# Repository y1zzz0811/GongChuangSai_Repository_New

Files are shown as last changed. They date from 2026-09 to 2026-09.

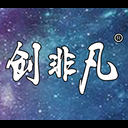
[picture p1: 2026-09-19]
参考资料/参考代码/视觉识别/视觉代码gxwl4看1抓1/app.png

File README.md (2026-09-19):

# 工创赛 · 智能物流搬运机器人

本仓库用于「中国大学生工程实践与创新能力大赛（工创赛）」智能物流搬运赛道的团队协作与代码、资料管理。

## 项目简介

智能物流搬运机器人，基于 STM32F407 主控，集成双轴机械臂、物料转台、麦克纳姆轮底盘与视觉系统，实现物料的自主识别、抓取与搬运。

## 目录结构

| 目录 | 说明 |
| --- | --- |
| [`代码`](代码) | 项目自行开发的源代码（当前为空） |
| [`设计图`](设计图) | 项目自行设计的三维模型与图纸（当前为空） |
| [`参考资料`](参考资料) | 参考代码、参考设计图、课程讲义、芯片手册、开源方案等 |
| [`规则说明与注意事项`](规则说明与注意事项) | 赛事规则、注意事项与团队约定 |

## 使用说明

- 嵌入式工程使用 Keil MDK-ARM 开发；编译中间产物已通过 `.gitignore` 忽略。
- 提交前请先 `git pull` 拉取最新代码，减少冲突。

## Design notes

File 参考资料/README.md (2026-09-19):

# 参考资料

存放学习与开发参考资料。

- [`参考代码`](参考代码)：STM32 例程、视觉识别例程等
- [`参考设计图`](参考设计图)：三维模型、装配体等
- 芯片手册、课程讲义、软件工具等

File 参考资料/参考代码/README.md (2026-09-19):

# 参考代码

存放用于参考的示例代码（当前项目尚未开始实际开发）。

- 嵌入式固件：STM32F407（Keil MDK-ARM / RT-Thread / HAL 库）
- 视觉与算法脚本：Python（MaixCAM）

> 编译中间产物（`.o`、`.axf`、`.hex`、`Objects/`、`Listings/` 等）已通过根目录 `.gitignore` 忽略，请勿手动提交。

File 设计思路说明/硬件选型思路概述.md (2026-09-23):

# 工创赛物流搬运小车硬件选型思路概述

## 一、总体选型思路

本次硬件选型并不是单纯追求“性能最高”的器件，而是在 **比赛任务需求、整车空间与重量、控制精度、开发难度和总体预算** 之间做平衡。2027 年智能搬运赛项要求机器人能够完全自主完成定位、移动、避障、二维码读取、物料颜色与位置识别、抓取、载运和精准放置等任务，因此视觉、机械执行和底盘定位三部分都需要具备足够的可靠性与可重复性。同时，规则对出发尺寸、单电源供电以及补光方向等也有明确限制，因此硬件必须兼顾集成度、体积和工程实现难度。

目前方案的核心思路可以概括为：**视觉部分优先追求单位预算下的有效算力和多摄像头扩展能力；机械臂部分优先考虑执行器重量、尺寸、速度和定位精度与塔吊式结构的匹配；底盘部分则优先保证运动控制和航向定位精度，在预算范围内尽量提高定位稳定性。**

---

## 二、视觉模块选型思路

视觉系统需要承担两类任务：一处摄像头负责二维码读取、障碍物识别及部分车身视觉定位；另一处摄像头负责物料颜色、物料位置、色环和放置位置识别。因此视觉方案的主要矛盾不是单纯“能不能识别”，而是 **如何在有限预算下同时完成两路视觉任务，并给后续算法留出一定性能余量**。

我们重点比较了 OpenMV、K230、MaixCAM 以及树莓派一类 SBC（Single Board Computer，单板计算机）视觉方案。OpenMV 的优势是生态成熟、开发简单，但在价格与 K230 接近的情况下，K230 的计算性能和后续扩展能力更强；MaixCAM 的性能和软件生态也较好，但整体价格更高；树莓派等 Linux 单板计算机的通用性最强，但主板、摄像头、存储和供电等整体成本明显增加，不符合当前视觉预算。

因此当前更倾向 **01Studio K230 + 双 GC2093 摄像头**。K230 的一个重要优势是单板具备多摄像头接口资源，可以让一块视觉板同时承担车身视觉和夹爪视觉两部分任务，从而减少额外视觉主控的数量，压缩成本和体积。现阶段的思路是先尝试由一块 K230 完成两路视觉处理；如果实际测试发现两路同时运行时会明显降低帧率或影响识别稳定性，则优先通过软件调度将两路任务错峰执行，因为扫码、障碍物识别、物料抓取和放置本身并不一定在同一时刻发生。若二维码识别仍然占用过多计算资源，也可以增加 GM65 等专用扫码模块，将二维码任务从主视觉中剥离，使 K230 主要负责颜色、位置和几何特征识别。

所以视觉部分的核心选型逻辑是：**先利用 K230 的高性价比和多摄能力实现一板双摄，在满足识别效果的前提下尽量减少视觉主控数量；若性能不足，再优先通过任务分时或专用扫码模块进行功能拆分，而不是一开始就增加更昂贵的计算平台。**

补光方面，由于比赛规则只允许垂直向下补光，因此补光主要服务于下视物料与色环识别，采用 LED 补光模块稳定照明环境，减小赛场光照和物料色差对颜色识别的影响。前视二维码部分不采用主动前向补光，而更多依靠曝光、增益和图像算法优化。

---

## 三、机械臂电机与舵机选型思路

我们的机械执行机构并不是传统多关节串联机械臂，而是更接近 **塔吊式直线运动结构**，主要包含竖直升降、水平伸缩、整体 Yaw 旋转、夹爪开合以及托盘转动。因此执行器选型不能简单套用“机械臂全部用同一种电机”的思路，而需要针对不同运动轴分别考虑。

这一部分主要关注四个因素：

1. **电机自重及其对机构平衡和惯量的影响。**  
   塔吊结构的运动部件越轻，升降和伸缩时所需驱动力越小，启停振动也越容易控制。尤其是水平伸缩轴，电机和夹爪如果过重，会明显增加悬臂负担。因此在满足扭矩的前提下，应尽量使用更小、更轻的执行器。

2. **电机体积是否与机械结构匹配。**  
   2027 规则要求机器人出发时投影尺寸不超过 300 mm × 300 mm、高度不超过 400 mm，因此初始收纳空间有限。28、35、42 等不同规格步进电机在尺寸和重量上的差异会直接影响机械设计和整车布置。

3. **定位精度和重复性。**  
   物料最终放置位置按照圆环精度评分，因此机械臂各轴不仅要“能运动到附近”，更重要的是重复到达同一位置时误差要足够小。闭环步进电机自带编码反馈，可以降低丢步风险，更适合升降、伸缩和旋转这类需要明确位置控制的轴。

4. **动作速度。**  
   比赛整体有时间要求，因此夹爪等只需要在少数固定位置之间动作的机构，没有必要全部采用较重的步进系统。高速舵机结构简单、自带位置闭环，适合夹爪开合和托盘旋转等动作。

基于这些考虑，目前方案采用分轴选型：  
- **Yaw 轴：42 闭环步进电机**，重点保证整体旋转定位的重复性；若后续发现重量对机构影响较大，可考虑高速大扭矩舵机作为减重备选。  
- **Z 轴升降：35 闭环步进电机**，升降负载中等，在重量和扭矩之间取平衡。  
- **水平伸缩：28 闭环步进电机**，该轴位于运动机构上，对轻量化更敏感，因此优先采用更小规格的电机。  
- **夹爪开合：10 kg 级高速舵机**，物料质量不超过 100 g，夹爪所需扭矩并不大，高速舵机可以减少开合动作时间，同时避免在末端增加过多重量。  
- **托盘旋转：25 kg 级舵机**，托盘需要带动物料并克服一定转动惯量，因此选择更高扭矩型号以保证动作稳定。

整体思路是：**需要连续精确位置控制的轴优先用闭环步进，需要快速完成固定角度动作的机构优先用舵机；越靠近运动末端，越重视轻量化。**

---

## 四、底盘控制与定位选型思路

底盘方案采用 **80 mm 麦克纳姆轮 + 4 个 42 闭环步进电机**。麦克纳姆轮能够实现前后、横移和原地旋转三自由度运动，非常适合在赛道内进行小范围调姿和视觉对位；闭环步进则兼顾了低速控制、位置重复性和防丢步能力，在有限预算下比普通开环步进更适合作为精准移动平台。

之所以优先考虑底盘运动精度，是因为比赛最终不是只考“能否到达目标区域”，而是直接按照物料放置的圆环位置评分。规则中 1 环为 15 分，而随着偏差增大分数快速下降，因此车体停车位置、车身航向误差和机械臂末端位置都会直接转化为得分差异。也就是说，**底盘定位精度本身就是评分链条的一部分，而不是单纯的辅助性能。**

航向定位目前选择 **JY901S 九轴 IMU**。我们也比较过 HWT101 一类更偏向 AGV 航向测量的模块，HWT101 在零漂等性能上更有优势，但价格超出当前预算，因此现阶段选择 JY901S，在成本与性能之间折中。JY901S 可以直接输出融合后的航向角，配合底盘控制用于直线行驶修正和转向角度闭环。

这里需要强调的是，IMU 主要用于 **车身航向角 θ 的测量**，并不能独立解决 X、Y 平面位置。闭环步进编码器反映的是电机轴运动，在麦克纳姆轮发生打滑时也不能完全等价于车体真实位移。因此目前方案将其作为基础定位手段，同时给后续升级留出接口：如果测试中发现累计位置误差较大，可以进一步加入视觉辅助定位、独立编码轮等手段，通过多源信息对车体位置进行修正。

所以底盘与定位部分的总体思路是：**先依靠闭环步进保证运动执行精度，依靠 IMU 保证航向稳定，再根据实车误差决定是否增加外部位置反馈；优先把有限预算投入到真正影响停车和放置精度的环节。**

---

## 五、三部分方案之间的整体关系

视觉、机械执行和底盘定位三部分并不是独立选型，而是围绕“精准抓取—精准运输—精准放置”这一完整任务链协同设计：

- **视觉系统**负责回答“目标是什么、目标在哪里”；
- **底盘与 IMU**负责把机器人稳定地移动到目标附近，并保持正确车身姿态；
- **机械臂执行机构**负责在目标区域内完成精确抓取、升降、伸缩和放置。

在当前预算条件下，我们没有单纯选择性能最高的器件，而是优先寻找 **性能刚好覆盖任务需求、同时具有较好性价比和工程可实现性的方案**。K230 通过一板双摄降低视觉系统成本；不同尺寸的闭环步进电机根据各运动轴负载进行分级配置，减少不必要的重量；夹爪和托盘采用舵机降低结构复杂度；底盘则通过闭环步进与 IMU 提升运动和航向控制精度。

因此这套硬件方案的核心并不是某一个器件本身，而是 **在预算、性能、重量、空间和开发复杂度之间进行系统级取舍，并为后续实车测试后的升级保留余量**。第一阶段先保证整车可以稳定完成任务，再根据实际测试结果重点优化视觉并发性能、底盘累计定位误差以及机械臂各轴速度与精度，从而逐步提高整车比赛表现。

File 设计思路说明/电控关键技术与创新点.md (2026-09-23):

# 电控关键技术与创新点

智能物流搬运赛项 · 电控说明  
依据目前已讨论的底盘、机械臂、避障和软件方案。尚未装车。雷达型号、步进当量仍待实机填写，下面不把这些写成已经完成的技术。本方案不使用灰度传感器。

```mermaid
flowchart TB
    subgraph topRow[" "]
        direction LR
        startNode[一键启动] --> scan[启停区扫描] --> match{有对应路段}
    end
    subgraph botRow[" "]
        direction LR
        stay[留在启停区]
        lock[锁定路段] --> task[沿灰道搬运] --> back[返回同一启停区]
    end
    match -->|没有| stay
    match -->|有| lock
    style topRow fill:none,stroke:none
    style botRow fill:none,stroke:none
```

一次运行只锁定一套路段。锁定之后按任务顺序走完，中途不再改路。

```mermaid
flowchart TB
    subgraph coarseRow[" "]
        direction LR
        park[停在工位外侧] --> coarse[机械臂回转并伸出] --> hold[机械臂保持]
    end
    subgraph fineRow[" "]
        direction LR
        fine[底盘慢速平移] --> lockChassis[底盘锁定] --> drop[垂直升降]
    end
    hold --> fine
    style coarseRow fill:none,stroke:none
    style fineRow fill:none,stroke:none
```

粗对准使用标定角度和伸出量。细对准只移动底盘，放下之后不再推移物料。

---

## 1. 关键技术

电控集中在 STM32F407 上，用定时器和主循环分工，不把图像放进主控。

**底盘运动。** 四轮麦克纳姆轮以前进、横移、旋转为控制量，逆解到四轮；某轮超速时四轮同比缩小，避免方向被拉偏。闭环由内到外是轮速、航向和工位视觉。直道靠陀螺仪保持航向、编码器估计路程。不使用灰度传感器。

**任务与路线。** 任务顺序固定：读码、装载、粗加工、暂存、第二批、码垛、回到本次出发的启停区。障碍落在某条车道上，该车道即被堵死。车道数量有限，所以堵法的总数有限，但当前还不能确定具体有几种。路段表按实际堵法预先写好，启动后锁定一套，行驶中不重新计算。

**视觉。** 两路 K230 分开使用。侧视读二维码，并在出发前确认视场内的黑色圆柱。向下摄像头只在细对准时给出颜色，以及物料中心或圆环中心相对夹持点的像素偏差。结果打成带校验的串口帧，校验失败的帧丢掉。

**避障感知。** 二维激光雷达在车身不动时扫描一周，用约 50 mm 的弦长判断目标落在哪条车道。侧视只辅助确认自己看得到的候选。转盘和台面挡住的方向记为未看到。

**机械臂。** 回转用 42 步进，伸缩用 28 步进，升降用 35 步进，开合用舵机。三轴按柱坐标控制，升降按二倍程把末端位移算成主动件的 2 倍。位置以归零开关为起点的步数。粗对准用标定角度和伸出量，细对准不再转动手臂。

**安全互锁。** 机械臂动作和托盘旋转时底盘速度为零。细对准结束后才垂直下降。物料接触台面并松爪后，不再推移该件。显示任务码、抓取数和放置数，字符高度不小于 12 mm。

---

## 2. 创新点

**用有限路段表代替行驶中的重新规划。** 障碍出现在某条车道上，就把该车道堵死，只走剩余车道。车道数有限，堵法总数也就有限；具体有几种要等场地车道确定后再填进路段表，当前不写死组合编号。一次运行在出发前锁定与本次堵法对应的那一套，任务顺序不变。结果对不上已有路段，或行驶中与锁定结果矛盾，就停在灰色车道内，不临时改道。

**出发前静止扫描，而不是开到路口再看。** 启停区与出发投影都是 300 mm × 300 mm，原地转向会把车角带出蓝区。雷达自己转一周完成四周测距，底盘速度保持为零。摄像头视场盖不住四周，所以由雷达判断哪条车道被堵，摄像头只确认视场内的黑色圆柱。没有回波不当成通路。判别结果对不上已有路段，就留在启停区。

**被堵住的车道直接删除，不从障碍旁边挤过。** 灰色车道宽 400 mm。障碍位于车道中部时，两侧剩余宽度不足以让车身留在灰道内通过。电控因此不做贴障横移，只在剩余车道上选择已经写好的路段。障碍具体会出现在哪些车道，当前不作规定。

**粗对准和细对准分开，细对准时手臂不动。** 底盘先停在工位外侧，机械臂回转到工位角度并伸到接近半径，摄像头和夹爪的相对位置随之固定。剩余偏差只由底盘按向下摄像头慢速平移消除。细对准若再转手臂，摄像头会跟着动，和挪底盘一样都在改画面，所以这一段不叠加回转或伸缩。对准后锁定底盘，手臂垂直升降。1 环只有很小的径向余量，而且接触台面后不能再推，所以放环用更低的速度，并在松爪后直接升起。

**灰色车道上不循黑线。** 行驶方向靠陀螺仪，路程靠编码器，工位毫米级偏差靠向下视觉。这样直道速度和放环精度可以分开，不会用同一套循迹速度去对圆环。

**机械臂按柱坐标和二倍程控制。** 回转、伸缩、升降分别对应角度、半径和高度，主控不做多关节逆解。二倍程只改末端与主动件的比例。三层环形爪由一只舵机开合，直径和倾角不单独控制。取放点只有车上托盘的直角顶点，换料靠托盘旋转。

---

## 3. 计划书正文（写入 Word）

电控的创新点集中在路径选择和放置精度。障碍落在某条车道上则该车道堵死，各种堵法数量有限，出发前由激光雷达与侧视一次判别并锁定对应路段，行驶中不再改线，也不贴障通过。机械臂完成粗对准后保持姿态，底盘再按向下摄像头消除剩余偏差，锁定后垂直放下，使物料对准圆环且放下后不再推移。

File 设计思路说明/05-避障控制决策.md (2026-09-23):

# 避障控制决策方案

智能物流搬运赛项 · 电控设计稿  
状态：理论方案。雷达型号、扫描面高度、各车道区域和遮挡角均不在本文写死，装车并对照场地图后写入配置。

---

## 1. 设计前提

离开启停区后，底盘只在灰色车道上行驶，不进入白色或淡黄色区域。中间为十字灰色车道，宽 400 mm。

黑色圆柱障碍的尺寸为直径 50 mm、高 100 mm。障碍会出现在哪些车道，当前还不能确定。障碍在车道中部时，两侧空档不足以让车身留在灰道内绕过，因此不贴障通过。某条车道上出现障碍，该车道从本次地图中删除。

蓝色启停区有两处，抽签决定出发位置，返回同一处。车道数量有限，因此堵死组合的总数有限，但当前不能确定具体有几种，本文不列出组合编号。路段表按「出发位置 + 被堵车道」在车道确定后填写，一次运行只锁定一套。任务顺序不变，路段航向和距离在标定后填写。

感知为侧视 K230 加二维激光雷达。一键启动后、底盘仍在蓝色启停区内完成一次扫描，然后锁定路线。

```mermaid
flowchart TB
    subgraph obsTop[" "]
        direction LR
        see[车道上有障碍] --> block[删除该车道] --> table{能查到路段}
    end
    subgraph obsBot[" "]
        direction LR
        go[锁定后出发]
        again{再扫后能查到}
        again -->|能| go
        again -->|不能| stopNode[停在启停区]
    end
    table -->|能| go
    table -->|不能| again
    style obsTop fill:none,stroke:none
    style obsBot fill:none,stroke:none
```

车身不从障碍旁边挤过。锁定之后，行驶中不再更换路段。

---

## 2. 可行性

这个扫法可以用来锁定路线。它成立的范围是：发令时障碍已经立在车道上，并且雷达从该启停区能直接打到它们。

**扫描时车身不动。** 出发投影不大于 300 mm × 300 mm，启停区也是 300 mm × 300 mm。车身接近这个尺寸时，原地转向会把车角带出蓝区。扫描期间 vx、vy、ωz 都保持为 0。四周距离由雷达自身旋转一周得到，不靠底盘转向。

**扫描面落在圆柱中下部。** 圆柱只有 100 mm 高，扫描面高于此就打空。原料转盘高 80–100 mm、直径 300 mm，粗加工台和暂存台的台体同样会挡住扫描面后方的空间。被挡住的方向没有回波，记为未看到，不记为该方向可通行。转盘和二维码板的位置在规定范围内变化，两种出发位置的遮挡角分开标定。

**50 mm 的短弦和场地装置可以分开。** 距离 1.5 m 时，直径 50 mm 的圆柱张角约 1.9°；距离 2 m 时约 1.4°。所选雷达在最远标定距离上，对这个圆柱至少给出 2 个回波，弦长才稳定。转盘的可见弦长在 300 mm 量级，台面边为 150 mm 与 580 mm，二维码板为竖立 A4，这些回波不作为删车道的依据。雷达装在车内，出发时整车仍在 300 mm × 300 mm × 400 mm 以内。雷达只测距，不照亮场地。

**摄像头确认视场内的候选，不负责看全四周。** 侧视固定在车上，停车时只有一个视场。雷达候选落在该视场内时，再用黑色直立圆柱的外形确认，两者一致才把该点所在车道记为堵住。候选在视场外时，用雷达弦长、所在车道区域，以及离开台面屏蔽区这三条一起判定，并要求连续两圈落到同一条车道。台面角点也可能呈现接近 50 mm 的短弦，所以短弦还必须落在车道的标定区域内、并位于台面屏蔽区之外。

**使用前提。** 命题写明障碍的数量和位置由抽签放置，没有写摆上的时刻，也没有写一定会落在哪几条车道。本方案按「开始扫描时障碍已经在车道上」实施。若现场在车辆离开启停区之后才摆障碍，这次扫描无效。

**扫不清就留在启停区。** 被堵车道都能归入已有路段表时，才锁定路段并出发。否则在启停区内再扫一圈。第二圈仍不能对应，就停在启停区，不进入未确认的车道。

---

## 3. 地图与路线表

车道在标定场地图时编号。车道名字、工位属于哪条车道、每种出发位置下雷达坐标到场地坐标的变换，都在那时确定。当前不规定障碍一定出现在哪几条车道，也不规定一次有几处。

查表键为「出发位置 + 被堵车道的集合」。某种堵法若使某一工位无法沿剩余车道到达，该组合标为不可用，车留在启停区。组合总数有限，具体几种在车道确定后写入，本文不列表。

任务顺序仍为：读取二维码，原料区装载，粗加工区放置并取回，暂存区平面放置，第二批装载、放置并取回，暂存区码垛，返回本次启停区。

---

## 4. 一次扫描如何归入车道

雷达输出一圈的角度和距离。相邻点角度间断超过标定间隙，或距离突变，就分成不同的簇。一簇两端点的弦长为

```
d = sqrt(r1^2 + r2^2 - 2 * r1 * r2 * cos(dθ))
```

弦长落在圆柱标定区间内的簇作为候选。簇的代表点取平均距离和平均角度，再变到场地坐标：

```
x = r * cos(θ + θ_mount)
y = r * sin(θ + θ_mount)
X = x0 + x * cos(yaw0) - y * sin(yaw0)
Y = y0 + x * sin(yaw0) + y * cos(yaw0)
```

`θ_mount` 是雷达零位相对车头的安装角。`(x0, y0, yaw0)` 是该出发位置在场地中的标定位姿。点落在哪条车道的标定长条内，就归到哪条车道。落在转盘、两处台面或二维码板屏蔽区内的簇丢弃。

落在侧视视场内的候选，交给侧视做黑色圆柱外形判定，判定方法与软件方案中的侧视一致。外形不符则该簇丢弃。

连续两圈归入的车道相同，才进入锁定。

```mermaid
flowchart TB
    subgraph scanTop[" "]
        direction LR
        startNode[读出发位置] --> still[底盘速度为零] --> scan[雷达扫两圈] --> assign[归入车道]
    end
    subgraph scanBot[" "]
        direction LR
        cam{侧视能看到} -->|是| vision[确认圆柱]
        cam -->|否| lidarOnly[按雷达保留]
        vision --> known{两圈一致且有路段}
        lidarOnly --> known
        known -->|是| lock[锁定出发]
        known -->|否| stay[留下或再扫]
    end
    assign --> cam
    style scanTop fill:none,stroke:none
    style scanBot fill:none,stroke:none
```

---

## 5. 行驶中的约束

锁定之后按该路段的航向行驶，陀螺仪保持航向，编码器估计路程。对接物料、对接圆环、机械臂动作和托盘旋转期间底盘锁定。

行驶中若测到的通断与已锁定结果矛盾，停车，留在灰色车道内。不改为贴障通过，也不进入黄区或白区，不在行驶中更换路段。

---

## 6. 计划书正文（写入 Word）

障碍出现在某条车道上，则该车道从本次路线中删除，车身不从障碍旁边挤过。车道数量有限，堵死组合的总数有限，具体有几种在场地确定后写入路段表。一键启动后车辆停在蓝色启停区内，二维激光雷达扫描一周，按约 50 mm 的弦长和标定区域判断被堵车道，侧视摄像头确认视场内的黑色圆柱。连续两圈结果一致且能对应已有路段后锁定，再离开启停区，本轮不再改变。扫描面低于圆柱高度，被转盘或台面挡住的方向记为未看到。结果对不上路段表时，车辆留在启停区。其后底盘只在灰色车道内按锁定路段行驶，对接与机械臂动作期间不因避障转向。

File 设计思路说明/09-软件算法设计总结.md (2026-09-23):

# 软件算法设计总结

智能物流搬运赛项 · 电控  
对应计划书第 9 节。下文只列本项目会用到的算法。尚未装车。本方案不使用灰度传感器，也不做灰度巡线。

图像算法在两路 K230 上运行。STM32F407 做状态机、底盘闭环、雷达归车道和机械臂脉冲，只接收带校验的视觉结果。

```mermaid
flowchart TB
    subgraph srcRow[" "]
        direction LR
        side[侧视] --> frame[校验后的数据帧]
        down[向下摄像头] --> frame
        lidar[激光雷达]
    end
    frame --> mcu[主控状态机]
    lidar --> mcu
    subgraph outRow[" "]
        direction LR
        route[锁定路段]
        chassis[底盘闭环]
        arm[机械臂脉冲]
    end
    mcu --> route
    mcu --> chassis
    mcu --> arm
    style srcRow fill:none,stroke:none
    style outRow fill:none,stroke:none
```

校验失败或当前用不到的帧直接丢掉。侧视负责任务码和黑色圆柱，向下摄像头只在细对准时给出颜色和中心。

```mermaid
flowchart TB
    mode{当前任务}
    mode --> obs[出发前归车道]
    mode --> qr[读码校验]
    mode --> color[抓取取色块中心]
    mode --> ring[放环取环心]
    mode --> stack[码垛取同色中心]
    obs --> lock[查表或留下]
    qr --> show[显示任务码]
    color --> move[底盘平移]
    ring --> move
    stack --> move
```

---

## 1. 路径

**任务状态机。** 顺序固定为读码、装载、粗加工、暂存、第二批、码垛、返回本次启停区。出发位置和障碍只改变所走路段，不改变这个顺序。

**路段查表。** 障碍所在车道视为堵死。车道数有限，堵法总数有限，具体几种等场地确定后再写入。查表键是「出发位置 + 被堵车道」。出发前锁定一套，行驶中不重新规划。结果对不上表，或中途与锁定结果矛盾，就停在灰色车道内。

## 2. 底盘

**麦轮逆解与限幅。** 由前进、横移、旋转求出四轮速度。某一轮超过最大转速时，四轮乘同一比例缩小。

**梯形速度。** 路段行程按加速、匀速、减速行驶。靠近工位改为爬行，放环时再降低速度。

**分层闭环。** 由内到外三层：轮速按编码器偏差调节 PWM；航向按陀螺仪偏差调节旋转；细对准时按向下摄像头的像素偏差调节慢速平移，进入阈值后底盘锁定。没有灰度边界这一层。

## 3. 障碍与视觉

**雷达归车道。** 一圈扫描按角度和距离断点分成点簇，用簇两端的弦长区分直径约 50 mm 的圆柱与转盘、台面。代表点变到场地坐标后，落入某条车道的标定区域即记该车道被堵。转盘和台面的屏蔽区内的点丢掉。看不到的方向记为未看到，不记为通路。连续两圈一致才锁定。

**黑色圆柱外形。** 侧视在视场内做低亮度掩膜，保留面积和长宽比符合直立圆柱的轮廓，用来确认雷达候选。视场外的候选只按雷达规则处理。

**任务码校验。** 侧视读取二维码后，检查是否为四组三位数、数字均在 1 到 6、组间用加号连接。连续两帧相同才采用。1 到 6 对应红、黄、蓝、绿、黑、浅蓝。

**物料颜色与中心。** 向下摄像头对六种颜色做阈值分割，取夹持点附近最大的实心色块。蓝色和浅蓝重叠时用亮度分开。中心用轮廓矩，再减去夹持点像素。

**圆环中心。** 放置前对台面边缘做椭圆拟合，把圆心聚在一起的同心椭圆取平均，作为环心。码垛时改为同色物料的色块中心。

**细对准换算。** 像素偏差只在机械臂已经完成粗对准、回转和伸缩保持不动时使用，换成底盘的慢速平移。机械臂运动过程中的画面丢掉。

**串口校验。** 视觉结果以固定帧头加异或校验上传。校验失败、长度不对，或当前状态不需要视觉时，整帧丢弃。

## 4. 机械臂

**柱坐标脉冲。** 回转、伸缩、升降分别对应角度、半径和高度，目标统一换成步进脉冲。升降末端位移按主动件的 2 倍计算。三只电机为回转 42 步进、伸缩 28 步进、升降 35 步进，开合为舵机。

**梯形步进与归零。** 脉冲间隔按梯形曲线变化。每轴以归零开关为步数零点，上电时先收回伸缩，再回转，最后升降。

**开合时序。** 舵机只有张开、闭合两档。闭合指令发出后保持一段标定时间，才允许上升。

**动作互锁。** 回转前伸缩必须收回、升降必须到安全高度。外伸之后才进入底盘细对准。细对准结束并锁定底盘后，才允许垂直升降。手臂未离开托盘直角顶点时，托盘不旋转。

---

## 5. 计划书正文（写入 Word）

软件算法分为路径、底盘、视觉和机械臂四部分。图像处理在两路 K230 上完成，主控只接收带校验的结果。路径使用状态机查表：障碍堵住的车道被删除，出发前锁定一套路段，行驶中不重新规划。底盘采用麦轮逆解，并以轮速、航向和工位视觉分层闭环，细对准时把像素偏差转为慢速平移。障碍由雷达点簇的弦长归入车道，侧视确认黑色圆柱；向下摄像头用颜色阈值和轮廓中心定位物料与圆环。机械臂按柱坐标生成步进脉冲，升降按二倍程换算，对准后只做垂直运动。

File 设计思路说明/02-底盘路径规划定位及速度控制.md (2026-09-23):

# 底盘路径规划、定位及速度控制方案

智能物流搬运赛项 · 电控设计稿  
轮径、轮距、各段航向与距离均不在本文写死，装车并对照场地图后再填入配置。

---

## 1. 设计目标

底盘在灰色车道内完成全场转运，并在原料区、粗加工区、暂存区为机械臂提供稳定的作业停车。放置圆环的重复精度优先于直道速度。

已确定的相关条件：

- 四轮麦克纳姆轮全向底盘。
- 车上为三角旋转托盘，机械臂只在直角顶点固定工位取放；换料由托盘旋转完成。
- 场地原料转盘由赛会提供，与车上托盘无关。
- 向下摄像头负责颜色与物料、圆环定位；侧视摄像头负责二维码与障碍。侧视辅助定位保留接口，暂时不启用。
- 避障为侧视摄像头加二维激光雷达，在离开启停区前扫描一次并锁定路段。

---

## 2. 坐标系与运动学

原点取底板几何中心，X 为前进方向，Y 为向左横移，Z 向上。车体指令为前进速度 vx、横移速度 vy、旋转角速度 ωz。

轮系采用 X 型镜像布置。四轮线速度（左前、右前、左后、右后）：

```
v1 =  vx - vy - ωz · (L + W)
v2 =  vx + vy + ωz · (L + W)
v3 =  vx + vy - ωz · (L + W)
v4 =  vx - vy + ωz · (L + W)
```

L、W 为轮心到原点的纵向、横向距离，D 为轮径，装车后实测写入配置。转速 n = v / (π · D) · 60。

vx、vy、ωz 分别限幅。若某轮超过最大转速，四轮按同一比例缩小，使实际运动方向与指令一致。航向以陀螺仪为准，编码器积分只作路程估计。

装车后的验收顺序：只给前进、只给横移、只给原地旋转。方向不对时先检查轮组安装与电机正反，再进入闭环调试。

---

## 3. 定位

中间十字灰色车道宽 400 mm，车道以外为白色或淡黄色。离开启停区后，车身铅垂投影不得进入这些浅色区域。场上没有供循迹的黑色引导线。

| 传感器 | 作用 | 使用阶段 |
|---|---|---|
| 陀螺仪 | 保持本段目标航向，抑制麦轮打滑造成的车头偏转 | 全程 |
| 编码器 | 轮速闭环；估计本段已走距离，用于接近工位时减速 | 全程 |
| 向下摄像头 | 物料与圆环中心偏差，换算为底盘微调 | 抓取与放置工位 |
| 侧视摄像头 | 读取二维码；在出发前扫描中确认视场内的黑色圆柱。辅助纠偏接口保留，第一版关闭 | 读码、出发前 |
| 激光雷达 | 出发前扫描一周，给出障碍相对车体的角度和距离 | 离开启停区之前，详见避障方案 |

行车阶段以航向闭环和路程估计为主。工位阶段切换为视觉偏差微调，到位后底盘速度为零。不用开环编码器脉冲完成圆环对准。

---

## 4. 路径规划

路径分为两层。

**任务层**按规则固定顺序推进，不随抽签改变。**路段层**只保存「从当前工位到下一工位」的目标航向和大致距离，进场对照地图标定，本文不给出具体角度和毫米数。抽签更换启停区时更换路段表，任务顺序不变。路线按已经锁定的路段表执行。

```mermaid
flowchart TB
    subgraph taskTop[" "]
        direction LR
        wait[等待启动] --> scan[锁定路段] --> qr[读取任务码] --> load[原料区装载]
    end
    subgraph taskBot[" "]
        direction LR
        rough[粗加工放置取回] --> temp[暂存平面放置] --> second[第二批与码垛] --> home[返回启停区]
    end
    load --> rough
    style taskTop fill:none,stroke:none
    style taskBot fill:none,stroke:none
```

扫描若对不上路段表，就停在启停区，不进入后面的工序。每个工位内部再走下面的对准流程。

```mermaid
flowchart TB
    subgraph dockTop[" "]
        direction LR
        arrive[停在工位外侧] --> arm[机械臂转伸] --> see[摄像头给出偏差]
    end
    subgraph dockBot[" "]
        direction LR
        move[底盘慢速平移] --> done{进入阈值}
        done -->|是| lock[底盘锁定] --> z[垂直抓放]
    end
    see --> move
    done -->|否| see
    style dockTop fill:none,stroke:none
    style dockBot fill:none,stroke:none
```

### 4.1 工位

| 代号 | 含义 | 停车要求 |
|---|---|---|
| HOME | 抽签确定的启停区 | 整车停在区内 |
| QR | 竖直二维码板 | 侧视能够读取，车身位置符合车道规则 |
| RAW | 赛会电动转盘 | 车身在车道内，机械臂能够到达转盘 |
| ROUGH | 粗加工区圆环 | 车身在车道内，机械臂能够到达指定环 |
| TEMP | 暂存区圆环 | 同上；第二批在此码垛 |

### 4.2 可复用的底盘动作

| 动作 | 内容 |
|---|---|
| 保持航向 | 速度为零，航向闭环 |
| 车道行驶 | 沿本段目标航向行驶，按编码器估计减速。不使用灰度传感器做横向修正 |
| 转向 | 低速转到下一段航向 |
| 爬行接近 | 进入工位前降速，停在机械臂能够粗对准的位置 |
| 视觉对接 | 机械臂保持粗对准姿态后，按向下摄像头偏差做小幅平移，进入阈值后停车 |
| 锁定 | 前进与横移为零，供机械臂和托盘动作 |

### 4.3 任务状态

N 为一次装载件数，默认 3，配置可改为 1。颜色与环号来自任务码，不在程序中写死。

1. **等待启动**  
   停在抽签启停区，等待一次启动。

2. **出发前扫描**  
   仍停在启停区，底盘速度为零。激光雷达与侧视确认被堵住的车道，并锁定对应路段。结果对不上路段表时留在启停区，不进入车道。

3. **进入车道**  
   按锁定路段离开启停区，进入灰色车道。

4. **读取任务码**  
   行驶至二维码板，由侧视摄像头读取并在车载屏幕显示。解析两批物料的颜色顺序和放置环号。读取失败时只做小幅调整并重试，超时后停车，不进入抓取。

5. **前往原料区**  
   按路段表行驶，停在转盘外侧。

6. **装载一批物料**（第一批、第二批各执行一次）  
   对第 i 个物料（i = 1…N）：
   - 将空托盘转到直角顶点，底盘锁定；
   - 机械臂升到安全高度，回转到原料工位并伸到接近半径，此为粗对准，期间底盘锁定；
   - 等待场地转盘把目标颜色送到可抓取位置；
   - 机械臂保持该姿态，底盘按视觉偏差慢速平移，进入阈值后锁定；
   - 机械臂垂直抓取并放入车上托盘，期间底盘保持锁定。  
   N 个全部上车后才允许离开原料区。

7. **前往粗加工区**  
   车上载有物料时降低加速度。

8. **粗加工区放置并取回**  
   对第 i 个物料：
   - 将对应颜色的托盘转到直角顶点，底盘锁定；
   - 从固定工位夹起，升到安全高度；
   - 回转并外伸到粗加工工位，完成粗对准；
   - 机械臂保持姿态，底盘对指定圆环做细对准，完成后锁定；
   - 垂直放置，该物料标记为已放置，不再产生推移动作；
   - 按任务顺序从圆环取回，放回车上托盘。

9. **前往暂存区并平面放置**（仅第一批）  
   对环与放置方式同粗加工区。放置完成后不再取回。

10. **第二批**  
   返回原料区，按任务码第三段重复装载；再到粗加工区，按任务码第四段重复放置并取回。

11. **暂存区码垛**（仅第二批）  
    目标为第一批同色物料的中心。对接后垂直放下，下降高度增加一个物料高度。

12. **返回启停区**  
    回到抽签确定的启停区，显示抓取数量和放置数量。

等待场地转盘单独作为状态，与故障停车区分。机械臂做粗对准、升降、开合或托盘旋转时，底盘速度为零。细对准时机械臂保持姿态，底盘只做慢速平移。障碍在离开启停区前锁定路段，行驶中不改路线，也不贴着障碍横移。

---

## 5. 速度控制

直道和工位使用不同的闭环。直道靠航向和轮速，细对准才打开视觉层。本方案不使用灰度传感器。

```mermaid
flowchart LR
    phase{当前阶段}
    phase -->|直道| head[航向闭环]
    phase -->|细对准| vis[视觉平移]
    head --> wheel[轮速闭环]
    vis --> wheel
    wheel --> pwm[四轮PWM]
```

控制由内到外为三层：

1. 四轮转速闭环：编码器测速，输出各电机 PWM。  
2. 航向闭环：陀螺仪与目标航向的偏差输出 ωz。  
3. 视觉位置闭环：仅在对接物料和对接圆环时，把像素偏差转为小幅 vx、vy。

直道为中速。距工位约 150 mm 起改为爬行。圆环对接使用更低的速度，进入阈值后锁定，再由机械臂垂直下降。对接圆环是放置精度所在：1 环外径为物料最大直径加 3 mm，且物料底面接触台面后不得再移动，因此这段不与直道共用同一速度。

路程采用先加速、再匀速、再减速的速度曲线。控制周期：轮速闭环 1～5 ms，航向闭环 5～10 ms，任务状态 10～20 ms。视觉数据在串口接收中处理。

调试顺序：单轮转速，航向直行，车道行驶，最后视觉对接。参数装车后写入配置，本文不预设具体系数。

---

## 6. 与其他部分的接口

- 机械臂、托盘未结束动作时，底盘保持锁定。
- 向下摄像头只在对接状态被采用。
- 侧视摄像头向底盘提供任务码和障碍；辅助定位字段保留且默认无效。
- 激光雷达与避障逻辑见避障方案。扫描在离开启停区之前完成，行驶中不因避障改线。
- 显示任务码、抓取数、放置数由电控在对应状态刷新。

---

## 7. 计划书正文

本车采用四轮麦克纳姆轮，以前进、横移和旋转为控制量，经逆运动学分配至四轮，超速时同比缩放以保持运动方向。直道行驶以陀螺仪保持航向、编码器估计路程，车身保持在灰色车道内。不使用灰度传感器。工位对准使用向下摄像头，在低速下将物料或圆环中心偏差收敛后再锁定底盘，随后由机械臂垂直放置。一键启动后先在启停区内锁定被堵住的车道，再按路段表读取二维码、装载、放置、码垛并返回同一启停区。各段航向与距离对照场地图标定。工位上先由机械臂完成粗对准，再由底盘做视觉细对准。机械臂粗对准、升降和托盘旋转期间底盘速度为零。侧视摄像头用于读码，并在出发前确认视场内的障碍。

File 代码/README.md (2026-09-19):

# 代码

存放项目自行开发的源代码（当前为空）。

- 项目正式开始开发后，将嵌入式固件、视觉与算法脚本等提交到此目录。
- 现阶段可供参考的示例代码见 [`参考资料/参考代码`](../参考资料/参考代码)。

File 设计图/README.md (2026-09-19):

# 设计图

存放项目自行设计的三维模型与图纸（当前为空）。

- 项目正式开始设计后，将 SolidWorks 模型、装配图、电路图等提交到此目录。
- 现阶段可供参考的设计文件见 [`参考资料/参考设计图`](../参考资料/参考设计图)。

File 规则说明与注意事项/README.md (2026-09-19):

# 规则说明与注意事项

存放比赛规则与团队约定。

- 赛事规则、评分标准
- 注意事项、时间节点
- 团队协作规范与约定

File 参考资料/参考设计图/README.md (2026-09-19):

# 参考设计图

存放用于参考的三维模型与设计文件（当前项目尚未开始实际设计）。

- 三维模型查看器（`.exe`）
- SolidWorks 模型（`.SLDPRT` / `.SLDASM` / `.STEP`）
- 结构示意图、渲染图等

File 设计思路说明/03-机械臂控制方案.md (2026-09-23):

# 机械臂控制方案（初步）

智能物流搬运赛项 · 电控设计稿  
状态：初步方案。尚未装车、尚未写入车上程序。步距、链传动当量、舵机脉宽、各工位角度和高度依赖实机测量，本文不写死。

结构按本次说明：二倍程升降，两根纵向支架约束夹爪上下运动；夹爪装在横向支架上，齿轮链条实现前后伸缩；三层环形爪由上而下直径增大，相对竖直线倾斜，开合由一只舵机完成。回转使用 42 步进电机，伸缩使用 28 步进电机，升降使用 35 步进电机。

车上三角托盘仍由单独的舵机旋转，不属于这四只执行器。机械臂只在直角顶点取放。

---

## 1. 控制思路

三个步进轴是柱坐标，软件不做多关节逆解。

- 回转步进给出绕竖直轴的角度 θ。
- 伸缩步进通过齿轮链条给出沿臂伸出方向的位移，记为径向位置 r。
- 升降步进带动二倍程，末端竖直位移按主动件的 2 倍计算。两根纵支架只约束方向。
- 三层爪的直径和倾角是被动几何。舵机只做开、合两个位置。

软件中的目标是「θ、r、末端高度 z、爪开或合」。毫米和角度在一处换成脉冲。

粗对准和细对准分开，细对准不再转动机械臂。

粗对准把夹爪送到工位附近：底盘沿路段停到工位外侧，机械臂升到安全高度，回转到该工位角度，再伸到接近半径。这三步使用标定值，此时不看视觉偏差。

粗对准结束时，回转和伸缩保持不动，摄像头与夹爪的相对位置也就固定下来。剩下的偏差交给底盘，按向下摄像头的像素偏差做慢速平移，直到收进阈值，然后底盘锁定，机械臂只做垂直升降。这一段与底盘方案中的视觉对接一致。

细对准若再转动机械臂，臂上摄像头会绕回转轴移动，画面里的目标位置跟着变，效果与微调底盘相同，都是在改摄像头和目标的相对位置。因此细对准只移动底盘，不叠加回转或伸缩。底盘也不是到站后就一直锁定：机械臂在回转、伸缩、升降、开合时底盘速度为零；细对准的那一段底盘允许慢速移动。

```mermaid
flowchart TB
    subgraph armTop[" "]
        direction LR
        stop[停在工位外侧] --> lift[升到安全高度] --> yaw[转到工位角] --> ext[伸到接近半径]
    end
    subgraph armBot[" "]
        direction LR
        hold[手臂保持] --> chassis[底盘细对准] --> locked[底盘锁定] --> down[只做升降开合]
    end
    ext --> hold
    style armTop fill:none,stroke:none
    style armBot fill:none,stroke:none
```

前三步是粗对准，使用标定值。从「保持」开始，机械臂不再为了对准而转动。

步进没有编码器，位置只信任相对归零开关的步数。链条有间隙，粗对准的外伸从收回一侧单方向接近。

行车前手臂处于收拢姿态：伸缩收回，回转到停放角，升降停在整车高度允许的位置。出发投影不大于 300 mm × 300 mm、高度不大于 400 mm。

---

## 2. 四个执行器

| 轴 | 执行器 | 软件量 | 位置从哪里来 |
|---|---|---|---|
| 回转 | 42 步进 | θ | 归零开关起的步数 |
| 升降 | 35 步进 | z 末端 | 主动件步数，末端 = 2 × 主动件位移 |
| 伸缩 | 28 步进，齿轮链条 | r | 归零开关起的步数，按链传动当量换算 |
| 开合 | 舵机 | 开或合 | 两档脉宽；无反馈，靠保持时间 |

三只步进均按 1.8° 整步、一圈 200 步计入换算。驱动器细分在型号确定后写入配置。主控输出 DIR、STEP、ENABLE。带料和悬臂时保持使能，避免被自重拖离步数。

升降的 2 倍按机构传动比使用。装车后测量主动件行程和末端实际升高，若比值不同，只改这一个系数。伸缩的毫米当量、回转的每度步数同样装车实测后填写。

---

## 3. 坐标

原点在机械臂回转轴上。θ = 0 为归零开关处的方向，r = 0 为伸缩收到归零开关，z = 0 为升降归零时的末端高度，向上为正。

```
z = z_home + 2 · s_lift
r = r_home + s_ext
θ = θ_home + s_rot
```

直角顶点取放姿态记为 `(θ_tray, r_tray)`，各场地工位另有一组粗对准用的 `(θ_work, r_work)`，全部标定。

细对准不把像素偏差换成 Δθ 或 Δr。向下摄像头给出的像素偏差，按底盘方案换成车体方向的慢速 vx、vy。此时 θ、r 保持粗对准结束时的值。偏差进入阈值后 vx、vy 归零，底盘锁定，再只动升降。放环阈值比抓取更严，数值装车后填写。

---

## 4. 运动顺序

- 回转之前，伸缩在安全半径以内，升降在安全高度以上。这两段底盘速度为零。
- 外伸只在回转已经到达该工位角度之后进行。外伸期间底盘速度为零。
- 外伸结束后进入细对准，只允许底盘慢速平移，机械臂三轴脉冲停止。
- 细对准完成并锁定底盘之后，才下降。下降过程中 r、θ 和底盘都保持不动。
- 上升离开台面或托盘之后，才允许收回和回转。
- 托盘只在手臂离开直角顶点上方之后旋转。

速度使用梯形曲线。放环和插入托盘的最后一段用单独的低速。物料底面接触台面并完成松爪后，该件记为已放置，不再产生平移。

### 4.1 从场地抓取并放入车上托盘

```mermaid
flowchart TB
    subgraph grabTop[" "]
        direction LR
        park[停在工位外] --> up[升到安全高度] --> rot[转到工位角] --> ext[伸到接近半径]
    end
    subgraph grabMid[" "]
        direction LR
        fine[底盘细对准] --> lock[底盘锁定] --> open[张开] --> down[降到抓取高度]
    end
    subgraph grabBot[" "]
        direction LR
        close[闭合] --> lift[升起] --> back[收回] --> put[放入托盘]
    end
    ext --> fine
    down --> close
    style grabTop fill:none,stroke:none
    style grabMid fill:none,stroke:none
    style grabBot fill:none,stroke:none
```

抓取高度按转盘顶面加上物料高度标定。转盘总高在 80–100 mm 之间，正式数值现场测量后写入。从外伸到锁定之前，底盘处于细对准；锁定之后直到手臂重新收拢，底盘速度为零。

### 4.2 从托盘取出并放入圆环

```mermaid
flowchart TB
    subgraph placeTop[" "]
        direction LR
        tray[托盘转到顶点] --> pick[夹起并升起] --> stow[收到安全半径] --> face[转到工位]
    end
    subgraph placeBot[" "]
        direction LR
        reach[外伸] --> align[底盘对环] --> drop[锁定后下降] --> done[张开并记为已放]
    end
    face --> reach
    style placeTop fill:none,stroke:none
    style placeBot fill:none,stroke:none
```

松爪后先升到离开台面，再收回。

### 4.3 码垛

路径与放入圆环相同。下降目标为平面放置高度再加上一件物料的高度。对准点是已经放好的同色物料中心。松爪后先上升。

### 4.4 行车收拢

底盘允许起步的条件是：伸缩在收拢半径内，回转在停放角，升降在行车高度，三轴脉冲已经发完。任一轴还在运动，底盘速度保持为零。

---

## 5. 步进和舵机怎么驱动

主控为 STM32F407。三个步进共用一个节拍定时器，需要走步时翻转 STEP。DIR 在该段第一步之前写好。步间隔按梯形曲线变化。最高步频以电机不丢步为准，装车后确定。

每轴一个归零开关。上电顺序为先收回伸缩，再回转找开关，最后升降找开关。开关在最大步数内没有出现，三轴停住，不进入比赛流程。调试阶段完成归零并保持驱动器通电。一键启动后不做大范围归零。中途断电则步数作废，需重新归零。

舵机用定时器 PWM，只有张开、闭合两档。同一次比赛的三种颜色为同一种形状，共用一档闭合脉宽。发出闭合指令后保持一段标定时间，再允许上升。三层爪由这一只舵机一起开合，张开脉宽要让最大一层能避开物料。脉宽和保持时间装车后填写。

---

## 6. 和底盘、视觉、托盘的接口

- 机械臂回转、伸缩、升降、开合期间，底盘速度为零。
- 粗对准完成后，细对准只使用底盘慢速 vx、vy。此期间机械臂步数保持不变。
- 细对准结束后底盘锁定，然后才升降。
- 向下摄像头只在细对准时使用。回转、伸缩和升降过程中的画面丢掉。
- 托盘舵机只在手臂离开直角顶点后转动。取放点只有直角顶点一处。
- 高度和工位角来自标定表，按任务码选择第几件、几号环，不在运动中重算路径。

---

## 7. 装车后填写的参数

下列项目依赖实机，当前不填数，也不影响上面的分工。测量结果直接写入配置。

- 升降主动件的实际传动比，设计值按 2 使用。
- 伸缩每毫米步数、回转每度步数、驱动器细分。
- 三个归零开关所在的一端，以及收拢角。
- 舵机张开、闭合脉宽和闭合保持时间。
- 各工位的 θ、r、抓取高度、放环高度、一件物料的高度。
- 细对准的抓取阈值和放环阈值。
- 下降时爪体是否遮挡向下摄像头。若遮挡，细对准时爪保持张开，下降过程不再使用该画面。

---

## 8. 计划书正文（写入 Word）

机械臂由回转、伸缩、升降和夹爪开合四个动作组成。回转使用 42 步进电机，伸缩使用 28 步进电机，升降使用 35 步进电机，夹爪开合使用舵机。升降为二倍程，末端位移按主动件的 2 倍计算；两根纵向支架约束升降方向。夹爪为三层环形爪，由上而下直径增大，由一只舵机联动开合。车上取放只在三角托盘的直角顶点进行。粗对准时，底盘停在工位外侧，机械臂回转到工位角度并伸到接近半径。此后机械臂保持该姿态，剩余偏差由底盘根据向下摄像头慢速平移完成细对准，再锁定底盘，机械臂垂直升降完成抓取或放置。放入圆环时低速下降，松爪后升起，不再推移该物料。机械臂动作期间底盘速度为零。行车前手臂收回至出发尺寸允许的姿态。步进位置以归零开关为基准，步距与舵机脉宽装车后标定。

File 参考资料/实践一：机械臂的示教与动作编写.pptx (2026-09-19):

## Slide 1

智能物流搬运机器人应用
—机械臂示教与动作编写

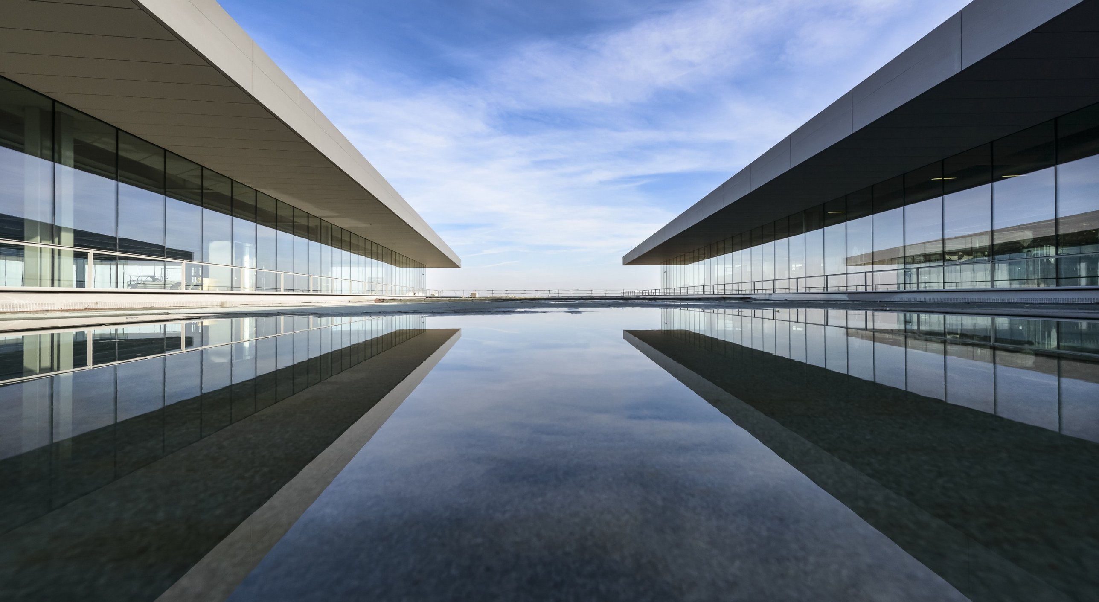
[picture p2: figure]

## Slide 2

01. 舵机调试接线

02.舵机ID号的修改

03.上位机功能按键

04.机械臂动作组

目录

CONTENTS

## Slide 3

01

舵机调试接线

## 舵机调试USB口，通过USB延长线与电脑连接

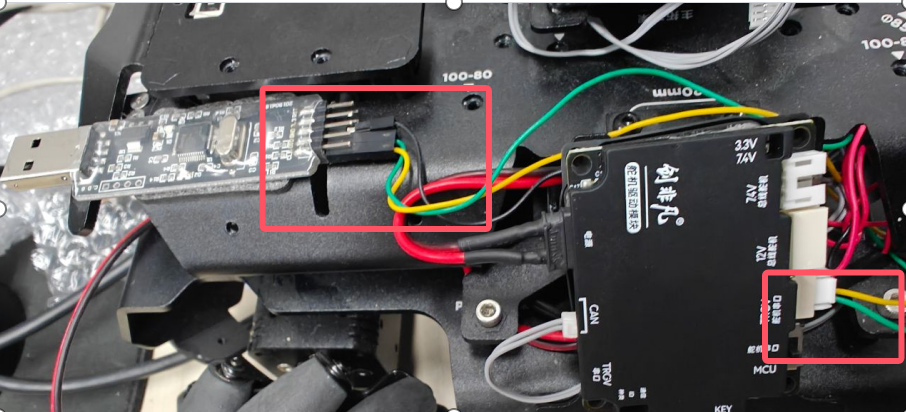
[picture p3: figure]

绿色对应TX，连接到信号板的TX接口，黄色对应RX，连接到信号板的RX接口，
G接GND，V不连接

## 舵机调试板拨码开关右拨（串口才能够检测到）

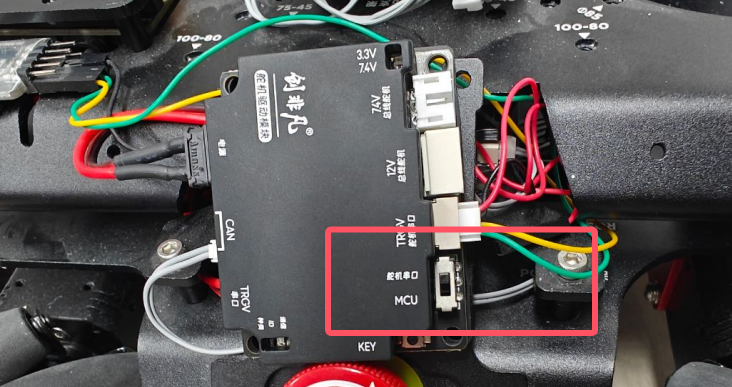
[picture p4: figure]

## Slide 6

02

舵机ID顺序

## 每个舵机出厂的默认ID都是1，为了实现串联控制，在将每个舵机串联在一起前必须先将4个舵机的ID分别单独设置为1、2、3、4（在设置舵机ID时将他与默认的舵机断开连接）

## 舵机以下图顺序进行连接

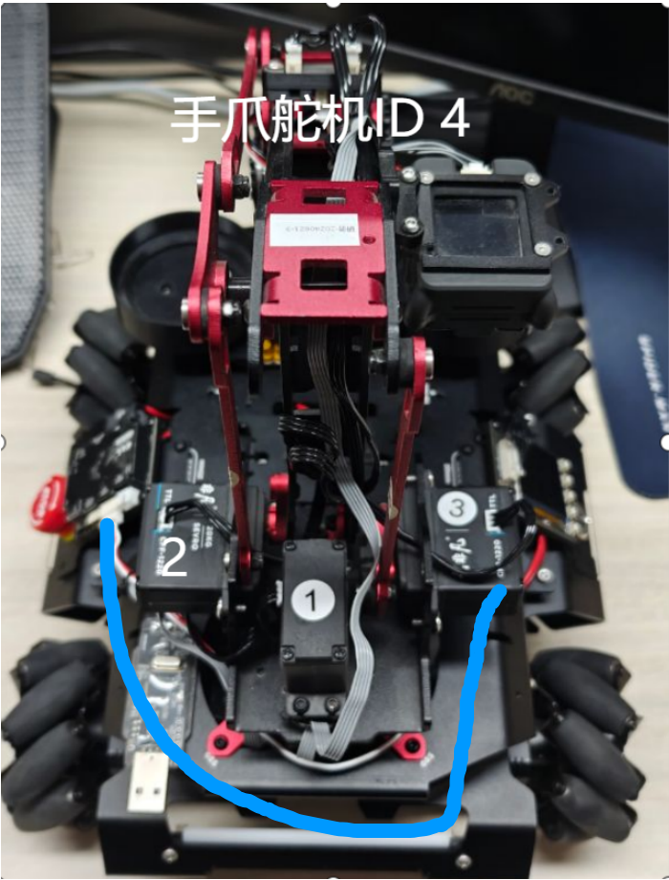
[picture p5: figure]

主信号线连接的先后顺序为3421。
图中蓝色标识的信号线为主信号线，将舵机驱动板与第一个3号位置的舵机连接。
3号舵机由另一端信号口与4号舵机连接。

## 按下开关，通过上位机进行舵机驱动板端口检测

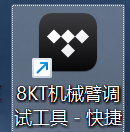
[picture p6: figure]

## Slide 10

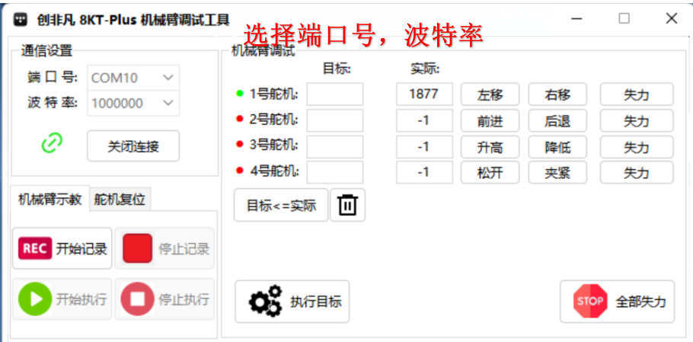
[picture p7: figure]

打开机械臂上位机软件，先进行端口号选择，波特率选择1000000，开启连接，如果舵机列表能检测到4个舵机，表示这个机械臂舵机ID号已经修改好了不需要再进行修改

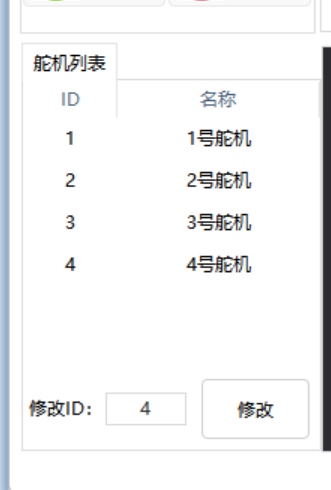
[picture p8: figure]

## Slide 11

上位机功能按键

03

## 各功能按键的使用方法

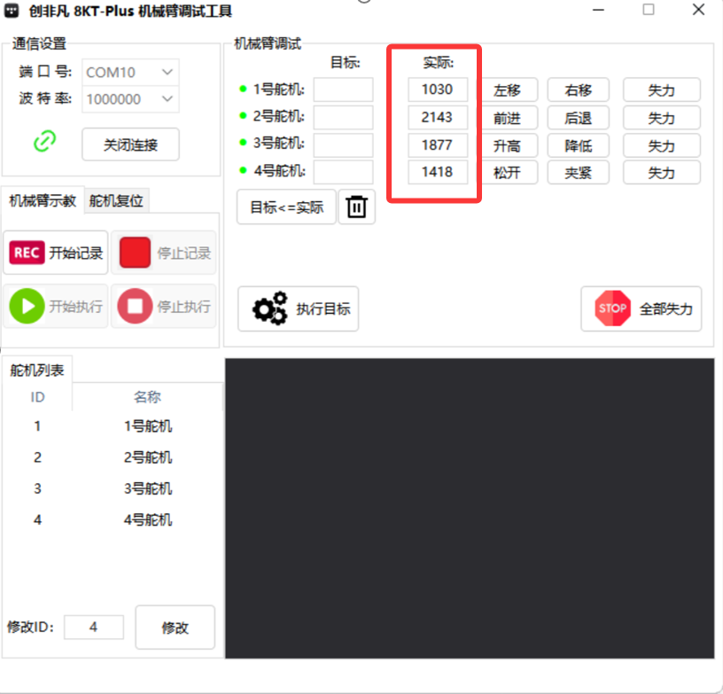
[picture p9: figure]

连接4个舵机后，上位机正常显示舵机数据。

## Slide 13

舵机复位

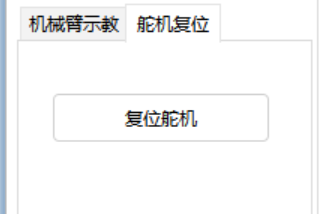
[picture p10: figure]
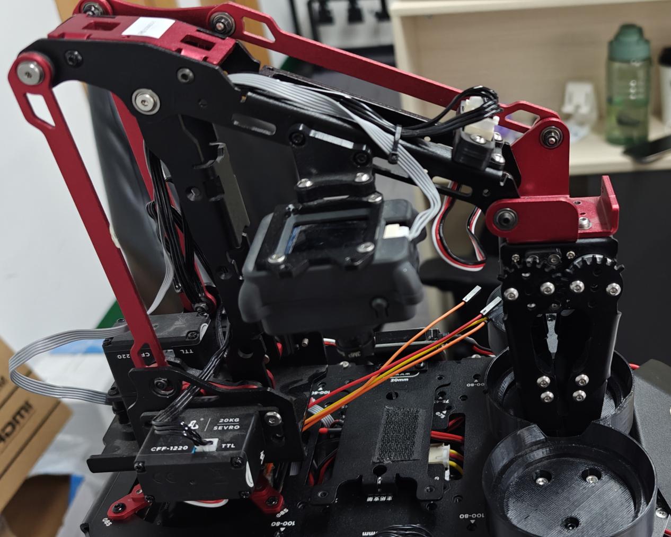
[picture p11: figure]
20eeb4a1009910f82198bbedf88eba1

将机械臂移动至一个固定的复位动作如图所示，点击复位，可实现多个机械臂相同参数所执行的动作相同，减少舵机角度调参的重复工作。方便机械臂动作组的编写，移植。如果换了其中一个舵机，也可以通过舵机复位，动作参数就不用重新修改。

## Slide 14

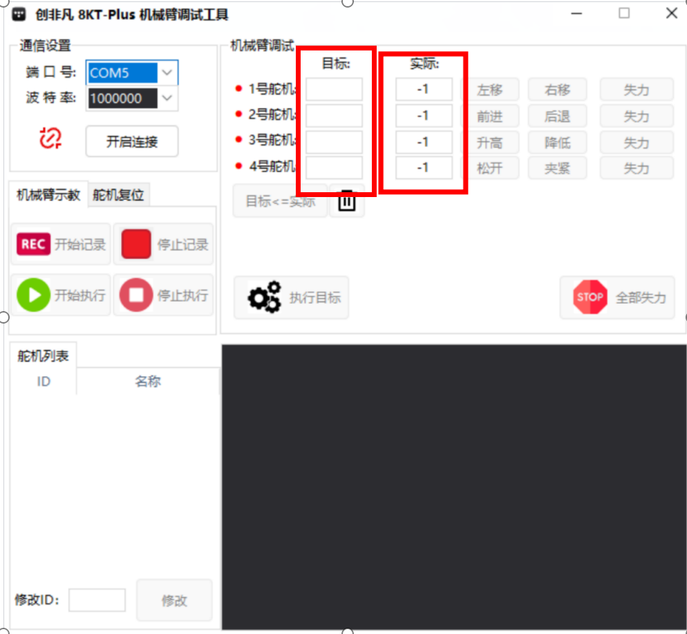
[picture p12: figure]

实际参数：
可实时显示舵机的位置参数，可以通过他对当前舵机的位置参数值进行记录，

目标参数：

点击上图所示按钮，可将当前实际参数赋值到目标参数，手动转动舵机角度，再点击

舵机会转动到目标参数，手动对目标参数进行修改点击执行目标，舵机便会转动到设置的目标位置

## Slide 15

当点击了执行目标时，舵机接收到了位置指令参数， 发生转动，到达目标位置，舵机自身有扭力，需要点击全部失力按钮，才可进行机械臂的手动移动， 在手动转动机械臂上位机实际列表中实时显示当前舵机角度的具体参数。

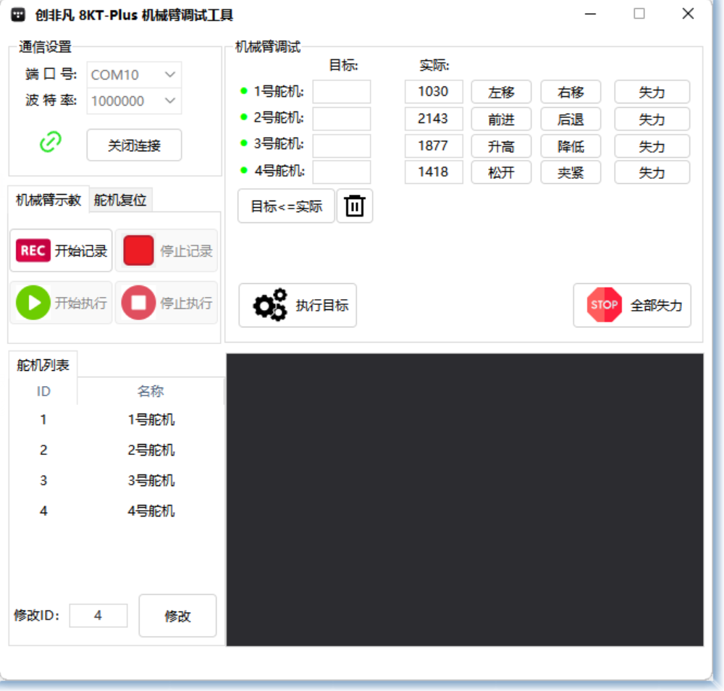
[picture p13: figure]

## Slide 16

04

机械臂动作组

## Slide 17

Run_1

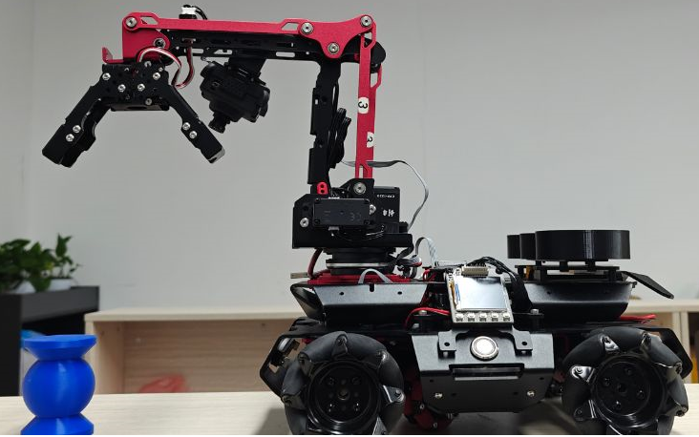
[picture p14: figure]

Run_2

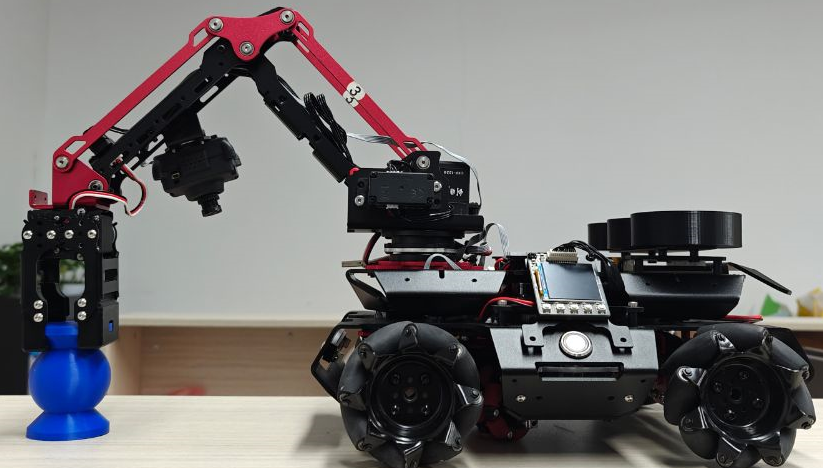
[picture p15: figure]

Run_3

Run_4

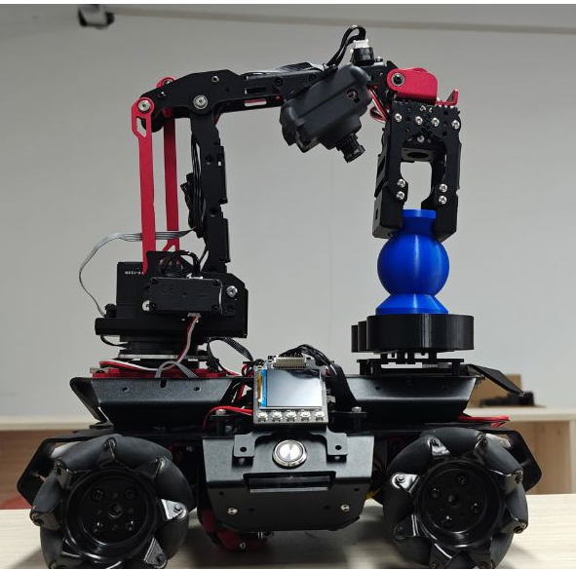
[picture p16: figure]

Run_5

5个抓取动作的编写，执行

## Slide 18

程序中的机械臂动作编写

打开程序文件夹

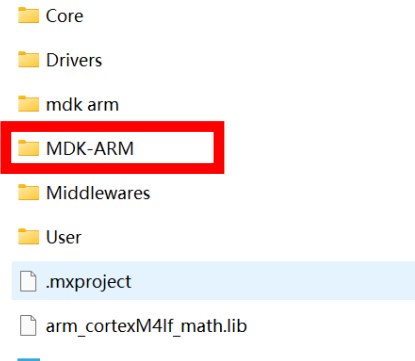
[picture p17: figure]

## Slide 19

左侧文件夹双击打开thread_user.c及Servo.c程序文件
thread_user.c主用户代码，会按顺序执行内部编写的指令
Servo.c机械臂动作组参数文件，动作组会在这个文件进行编写执行。

thread_user.c第711行开始执行机械臂程序

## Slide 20

static void Debug_Await(void)//暂停执行
{
while(KEY_5() == 0)
My_mDelay(50);
while(KEY_5() == 1)
My_mDelay(50);
}

当按下按键K5按钮，程序会运行到Run_1执行刚才编写的动作，运行完Run_1动作后会再次执行Debug_Await（）进行等待按键K5按下，再执行Run_2,

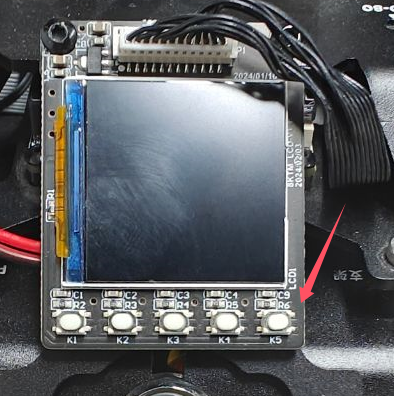
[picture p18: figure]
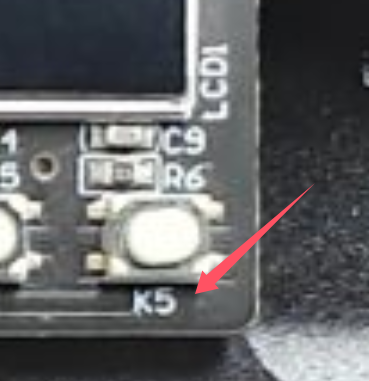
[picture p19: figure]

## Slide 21

在Servo.c文件18行的open代表手爪的张开参数800根据实际参数进行替换，close为闭合参数1370根据实际参数进行替换，将固定的参数重命名，方便后续动作编写。

在Servo.c文件316行的Run_1函数中可以编写机械臂舵机动作参数，如图所示
（舵机ID，位置参数，速度3250，加速度60）
速度范围（0-4500），加速度（0-180）
（速度增大加速度也要变大，机械臂运动速度加快）

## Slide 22

连接上位机，各显示舵机实时参数（参数就代表机械臂此刻动作），点击

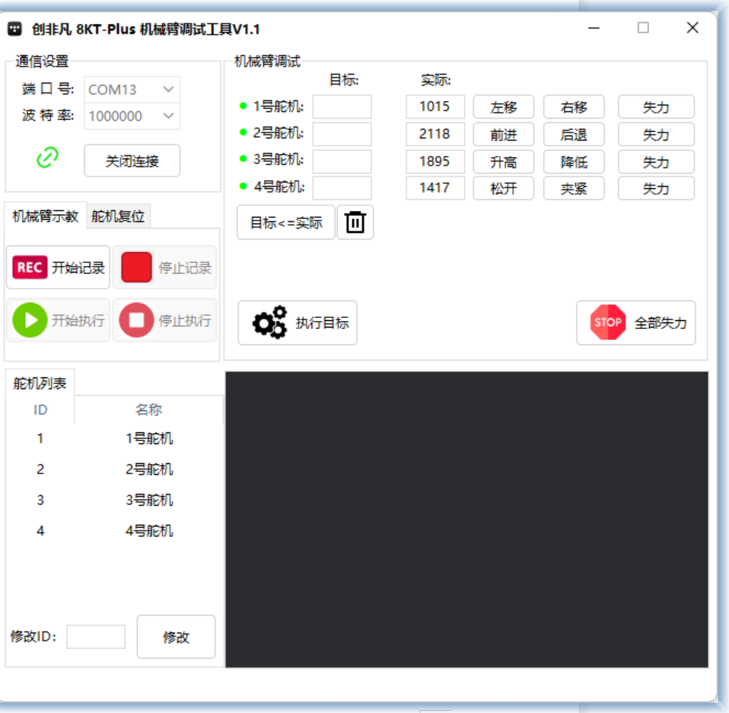
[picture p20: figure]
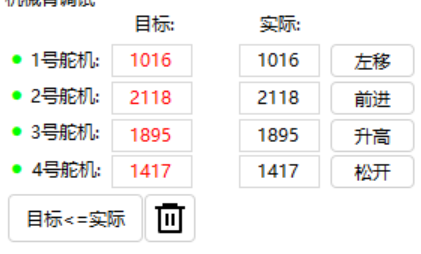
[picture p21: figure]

通过手动移动机械臂记录，移动到一个点位，将实际参数赋值到目标参数，将目标参数按顺序进行记录填写

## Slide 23

可以对红色目标参数双击选中进行复制按舵机ID顺序对应括号内的1234顺序填入Servo.c文件下的Run_1函数红色方框中。程序运行Run_1，通过函数将舵机参数值发送至舵机控制板，实现对舵机的驱动。括号内的参数（ID号，位置参数，速度参数，默认30）
将4个舵机参数分别写入到对应ID号舵机，舵机同时执行动作。

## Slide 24

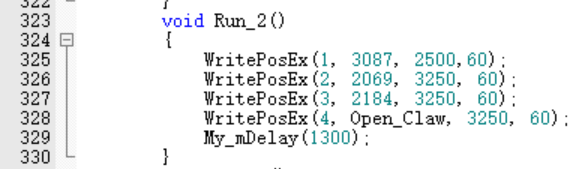
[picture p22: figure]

需要按下K5按键程序才会再往下执行，可以在Servo.c的Run_2函数中可以编写动作参数，复制Run_1的格式进行参数修改，机械臂会执行第二个点位的动作，以此类推完成一个对桌面物料的抓取动作

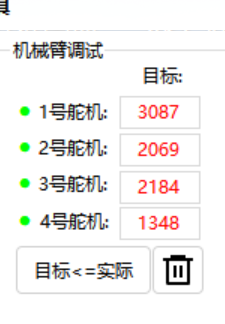
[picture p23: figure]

通过将实际参数赋值给目标参数，实际目标参数值进行Run_2内容参数的填写。

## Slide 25

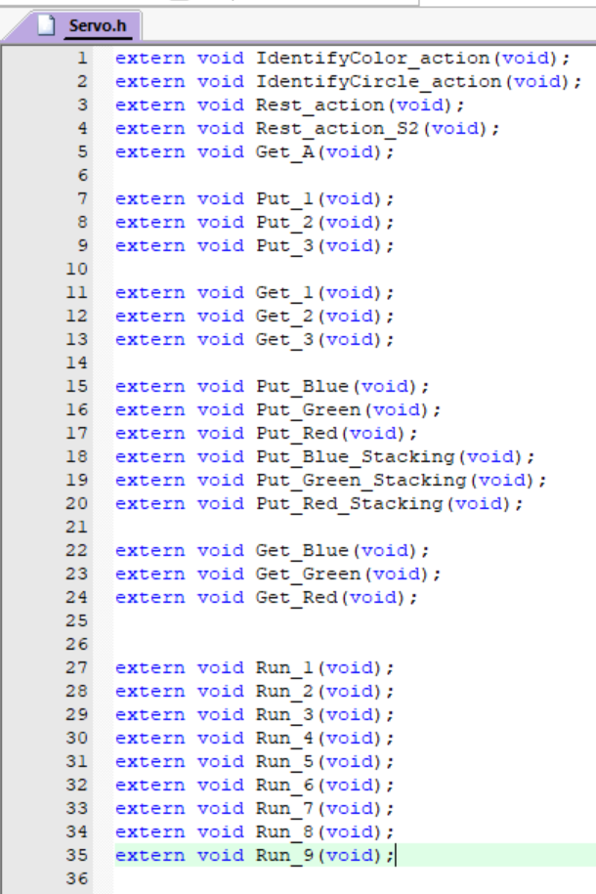
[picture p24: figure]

创建新函数名需要在Servo.h对函数进行外部声明

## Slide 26

Run_1动作

机械臂初始动作

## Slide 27

Run_2动作

机械臂准备抓取动作

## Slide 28

Run_3动作

机械臂抓取动作

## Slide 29

Run_4动作

机械臂抓取后抬升动作

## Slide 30

Run_5动作

机械臂抓取物料返回动作

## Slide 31

Run_1

Run_2

Run_3

Run_4

Run_5

5个抓取动作的编写，执行

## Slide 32

完成前面的基本动作，可在Run_6写入将物料放入料仓中的动作

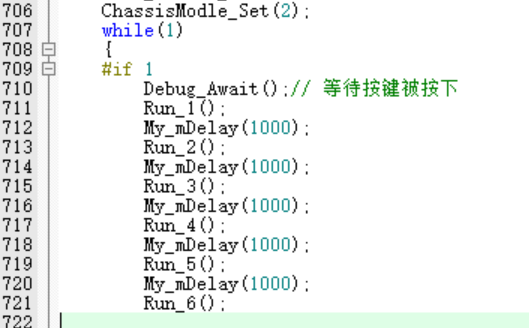
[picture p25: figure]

将Debug_Await替换为延时函数，My_mDelay(1000),实现机械臂连续动作

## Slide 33

int16_t Open_Claw = 2070;
int16_t Mid_Claw = 1700;
int16_t Close_Claw = 1550;
/* ------------------------------------------------------------*/
Servo bowl_1 = {//1号碗
773,
2200,
2172,//>>>>>2050
};
Servo bowl_2 = {//2号
1014,
2150,
2165,//>>>>>2050
};
Servo bowl_3 = {//3号
1251,
2200,
2164,//>>>>>2050
};

总线舵机「数值 ↔ 角度」精准对照表

数值范围：0 ~ 4095
对应角度：0° ~ 360°
换算公式：角度 = 数值 × 0.087912

名称ID4 | 舵机数值 | 实际角度 | 机械状态
Close_Claw | 1550 | 136.3° | 夹爪完全闭合
Mid_Claw | 1700 | 149.5° | 夹爪半开中间位
Open_Claw | 2070 | 182.0° | 夹爪完全张开

名称 ID1 | 舵机数值 | 实际角度 | 状态
最小位置 | 773 | 67.9° | 最低角度限位
最大位置 | 2200 | 193.4° | 最高角度限位
工作位置 | 2172 | 190.9° | 正常工作角度

名称 ID2 | 舵机数值 | 实际角度 | 状态
最小位置 | 1014 | 89.1° | 最低角度限位
最大位置 | 2150 | 189.0° | 最高角度限位
工作位置 | 2165 | 190.3° | 正常工作角度

名称 | 舵机数值 | 实际角度 | 状态
最小位置 | 1251 | 110.0° | 最低角度限位
最大位置 | 2200 | 193.4° | 最高角度限位
工作位置 | 2164 | 190.2° | 正常工作角度

舵机数值 | 角度 | 用途参考
1024 | 90.0° | 垂直 90 度
2048 | 180.0° | 水平中位
2050 | 180.2° | 你原设计中位
2160 | 190.0° | 碗舵机统一工作角
2070 | 182.0° | 夹爪全开

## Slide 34

完成前面的基本动作，可在Run_6写入将物料放入料仓中的动作

将Debug_Await替换为延时函数，My_mDelay(1000),实现机械臂连续动作

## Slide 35

完成前面的基本动作，可在Run_6写入将物料放入料仓中的动作

将Debug_Await替换为延时函数，My_mDelay(1000),实现机械臂连续动作

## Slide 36

任务要求：
1.完成前面的基本动作，可在Run_6继续编写具体的功能：将物料从桌面抓取，放置在料仓中，再将物料从料仓中取出放置到桌面动作。

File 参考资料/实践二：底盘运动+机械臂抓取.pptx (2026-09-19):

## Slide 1

智能物流搬运机器人应用
—底盘运动+机械臂


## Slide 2


01

底盘控制部分

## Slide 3


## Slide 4

通过修改坐标点参数控制底盘运动，坐标系xy的方向不随底盘旋转而改变。坐标系方向取决于小车开机摆放的朝向


通过ChassisCoord_Set();函数控制小车底盘进行坐标点运动

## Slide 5

底盘运动到坐标点需进行等待，函数用于检测底盘是否运动到了目标点，每跑一个坐标点后需要加等待函数。

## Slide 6

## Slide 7

02

机械臂抓取

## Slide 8


Run_1


Run_2


Run_3


Run_4


Run_5

5个抓取动作的编写，执行

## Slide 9


机械臂抓取动作组执行

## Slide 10


任务要求：
由出发区出发，根据地图箭头方向，移动到转盘位置，抓取1个物料，将转运到实验二存放区，放置在存放区黄色区域内，最后车身返回蓝色出发区

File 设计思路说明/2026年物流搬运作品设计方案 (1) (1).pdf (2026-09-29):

- 1 -
第十届中国大学生工程实践创新能力大赛 | 作品设计方案 Structure Design Scheme | 共 页 | 第 1 页
| | 赛 项 | 智能物流搬运赛项
第一幅照片（小车正面） | 1、设计思路（字体，宋体，五号，行距为固定值 20 磅，阅后删除）

## 2、小车底盘路劲规划定位及速度控制方案

本车采用四轮麦克纳姆轮，以前进、横移和旋转为控制量，经逆运动学分配至四轮，超速时同比缩放以保持运动方向。直道行驶以陀螺仪 保持航向、编码器估计路程，并预留车道边界检测，防止驶出灰色车道。工位对准使用向下摄像头，在低速下将物料或圆环中心偏差收敛 后再锁定底盘，随后由机械臂垂直放置。
路径按任务状态机执行：读取二维码，在原料区装载，于粗加工区放置并取回，在暂存区平面放置或码垛，最后返回启停区。各段航向与 距离对照场地图标定。机械臂动作和托盘旋转期间底盘速度为零。


第二幅照片（小车侧面）


## 3、机械臂结构及控制方案

机械臂整体圆柱坐标式结构，由旋转底座+升降轴+伸缩臂构成，通过两根纵向支架来约束夹爪的上下移动，两根支架以保持机械臂 稳定，夹爪安装在一横向支架上，通过齿轮链条传动实现夹爪的前后移动。夹爪采用三层环形爪组合而成，由上而下夹爪直径依次增大， 并与竖直线成特定倾角，以适应物料的结构特征，同时增大接触面积，提高夹取成功率。
机械臂由回转（42 步进电机）、伸缩（28 步进电机）、升降（35 步进电机）和夹爪开合（舵机）四个动作组成，驱动来源如括号 内容所示。车上取放在三角托盘的顶点进行。放置和夹取物料都由两步“粗对准+精对准”组成：粗对准时，底盘停在工位外侧，机械臂 回转到工位角度并伸到接近半径。此后机械臂保持该姿态，剩余偏差由底盘根据向下摄像头慢速平移完成细对准，再锁定底盘，机械臂垂 直升降完成抓取或放置。放入圆环时低速下降，松爪后升起，不再推移该物料。行车前手臂收回至出发尺寸允许的姿态。步进位置以归零 开关为基准，步距与舵机脉宽根据实装车的测量值确定。

- 2 -
第十届中国大学生工程实践创新能力大赛 | 作品设计方案

## Structure Design Scheme

共 | 页 | 第 2 页

## 4、硬件选型方案分析（为什么要选这个方案并列清单总额）

## 5、小车避障控制决策方案说明

障碍出现在某条车道上，则该车道从本次路线中删除，车身不从障碍旁边挤过。车道数量有限，堵死组合的总数有限，因此可以建立并维护路径表。一键启动后车辆停在蓝色启停区内，二维激光雷达扫描一周，按 约 50 mm 的弦长和标定区域判断被堵车道，侧视摄像头确认视场内的黑色圆柱。通过位置判定，能对应已有路段后锁定，再离开启停区，本轮不再改变。扫描面低于圆柱高度，被转盘或台面挡住的方向记为未看到。 结果对不上路段表时，车辆留在启停区。其后底盘只在灰色车道内按锁定路段行驶，对接与机械臂动作期间不因避障转向。

## 6、小车视觉方案分析

视觉采用 K230 + 双摄像头 + 激光测距构建视觉感知系统。
车身摄像头主要负责二维码识别及障碍物检测，结合激光测距获取障碍物距离，为小车导航与避障提供信息。在开始之初扫描二维码处旋转 180°摄像头观察障碍物位置 机械臂末端摄像头主要负责物料颜色识别、位置定位及目标放置区域识别。采用 LAB 阈值分割与色块检测获取物料中心像素位置，通过与预设目标位置比较，控制小车微调，使物料进入目标像素范围；放置时识别

目标圆环位置，通过视觉闭环调整实现精准放置。
针对初赛物料形状、尺寸固定且主要以颜色区分的特点，采用轻量化颜色识别方案，并通过脱机 LAB 阈值调节提高现场适应能力，同时预留 YOLO 算法用于决赛物料变化的扩展。 最终形成“环境感知—任务识别—物料定位—视觉对位—精准抓取”的视觉闭环。

## 7、参赛人员具体分工

覃祉璇：视觉部分
黄彦哲：电控部分
张景妍：电路设计及硬件选型
吕桂卿：机械部分

- 3 -

## 8、关键技术及创新点

（1）机械 本设计基于物料的结构特征，在夹爪结构设计上大胆创新，采用三层环形爪组合而成，由上而下夹爪直径依次增大，并与竖直线成特定倾角，以完美适配物料的光滑侧壁，提高夹取成功率；同时托盘 内壁采用上宽下窄的设计，托盘开口略大于物料最大直径，托盘底部直径等于物料最大直径，内壁具有竖直倾角，使物料下滑过程中自动回正，以实现精准放置，同时便于后续夹爪精准夹取。

（2）电控 电控部分在路径选择和放置精度上进行了创新：我们假设存在障碍物的支路被堵死，不考虑绕行。在这之后我们对障碍物出现的情况进行穷举，建立路径表并由主控维护，出发前由激光雷达与侧视一 次判别并锁定对应路段，行驶中不再改线，也不贴障通过。机械臂控制上通过“粗对准+精对准”的方式，同时保证搬运的效率和精确度。粗对准后保持姿态，底盘再按向下摄像头消除剩余偏差，锁定后垂直放下，

使物料对准圆环且放下后不再推移。

（3）视觉 关键技术包括双摄像头视觉感知、视觉与激光测距融合避障及视觉闭环对位。脱机 LAB 阈值调节与参数保存机制，可根据现场光照和物料色差快速调整视觉参数；结合视觉反馈实现物料精准对位与放

置，提高系统的环境适应性和稳定性。

## 9、软件及算法优化

软件算法分为路径、底盘、视觉和机械臂四部分：
视觉在两路 K230 上完成：根据机器人不同任务状态，分别进行二维码识别、障碍物检测和物料识别。物料及目标放置区域采用图像处理获取位置，通过像素坐标计算位置偏差，并采用“识别—调整—再识别”的 闭环方式完成精准放置；结合 ROI、图像预处理及 LAB 阈值调节，提高识别实时性和稳定性。
路径使用状态机查表：障碍堵住的车道被删除，出发前锁定一套路段，行驶中不重新规划。
底盘采用麦轮逆解，并以轮速、航向和工位视觉分层闭环，细对准时把像素偏差转为慢速平移。
机械臂将视觉识别，主控计算的坐标换算为柱坐标生成步进脉冲，升降按二倍程换算，对准后只做垂直运动。


- 4 - | 小车装配图（三维图） | 比 例
第十届中国大学生工程实践创新能力竞赛 | 共 | 页 | 第 2 页

- 5 -

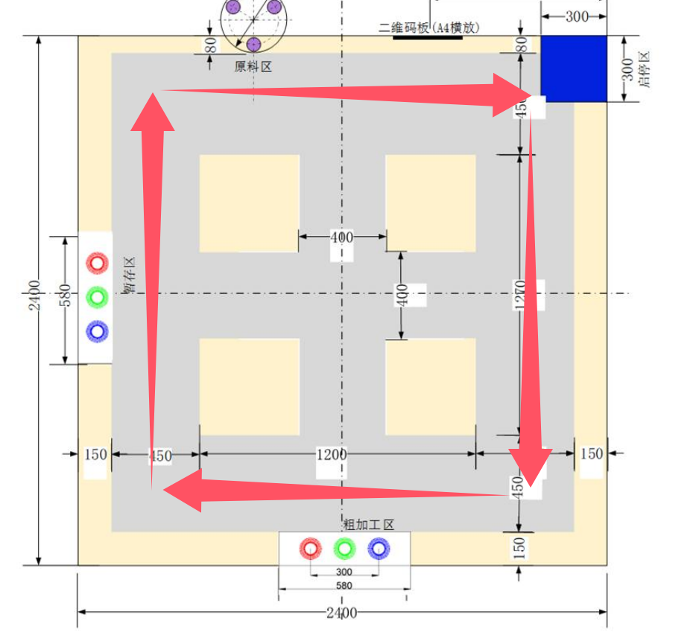
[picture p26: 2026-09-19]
参考资料/竞赛场地图.png

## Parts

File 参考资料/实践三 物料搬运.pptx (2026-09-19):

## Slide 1

物料放置实践


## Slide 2

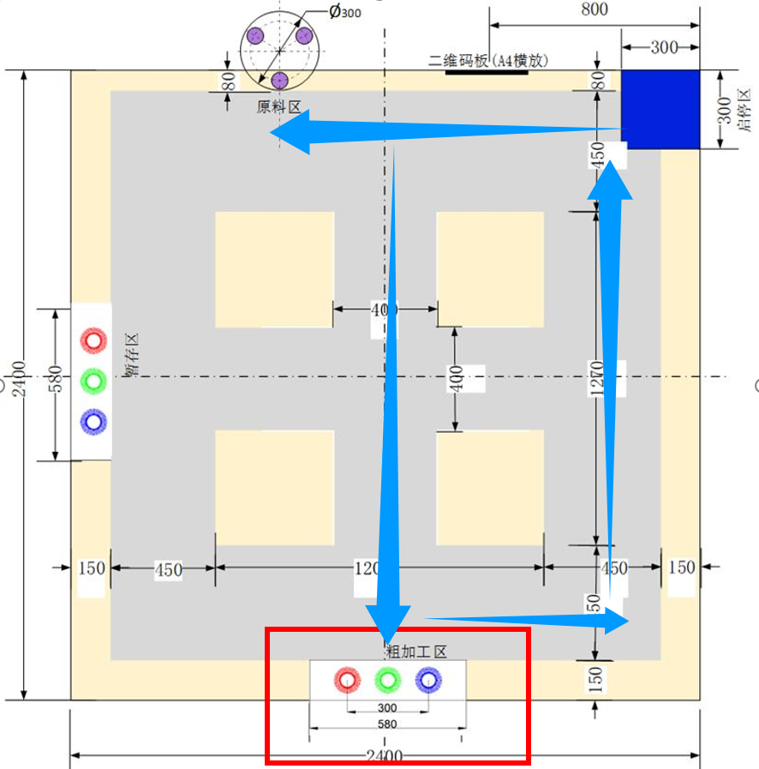
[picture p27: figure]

任务要求：
由出发区出发，移动到转盘位置，抓取3个物料，将转运到粗加工区，放置在对应色环内，再将物料按放置顺序取回，最后车身返回蓝色出发区

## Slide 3

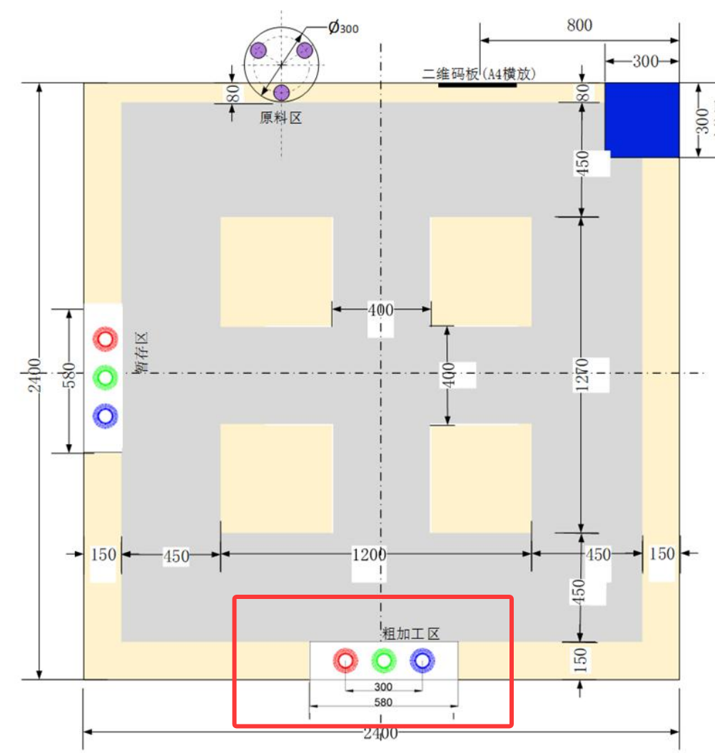
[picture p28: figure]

任务要求：
将车放置在图中框选的粗加工区，绿色色环前方的灰色行车道位置，开机，执行视觉纠正车身位置，机械臂将车身物料放置到色环，并抓回。

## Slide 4

代码解析

主函数部分，为主要执行的内容，
693行开始往下执行代码，
693代表停止视觉模块的所有任务
694舵机初始动作
695底盘设置为坐标模式控制
699通过按键按下程序才能够
继续往下执行，相当于启动按键。
703为机械臂识别绿色圆环的动作组

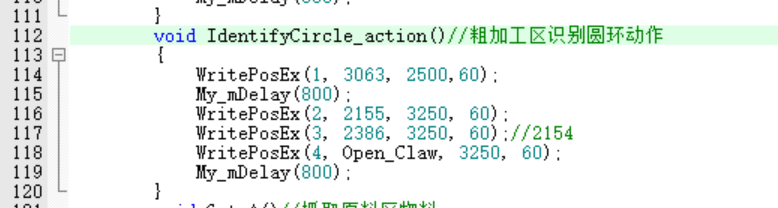
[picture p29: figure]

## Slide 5

执行圆心识别并纠正底盘位置函数（100,150）代表想要让视觉纠正的圆心坐标。在视觉模块上的像素坐标点。

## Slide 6

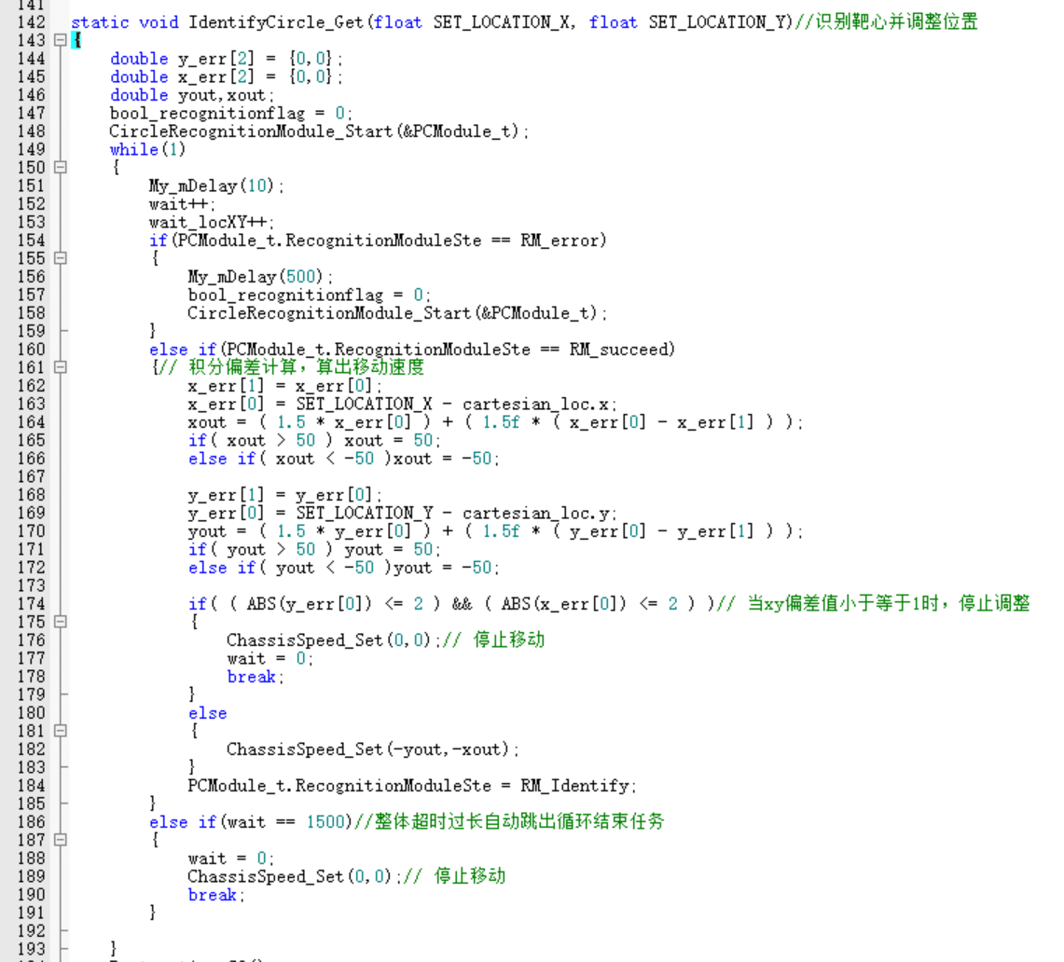
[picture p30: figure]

圆心函数说明
SET_LOCATION_X , SET_LOCATION_Y
为设定的目标圆心像素坐标点，
cartesian_loc.x , cartesian_loc.y
为实时反馈的视觉圆心识别坐标
将他们的误差作差，得到x_err[0],y_err[0],x与y方向的误差累计
通过比例系数转换，xout,yout为最终误差方向的速度差。
174行，判断ABS绝对值误差小于2，则满足误差范围退出，ChassisSpeed_Set(0,0);//底盘以0的速度运行，即停止底盘运动。
如果不满足误差范围，则根据误差值作为底盘移动修正速度，误差越小底盘速度越小，最终误差满足范围条件，停止底盘运动，达到通过视觉识别，修正位置的效果。

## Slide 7

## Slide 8

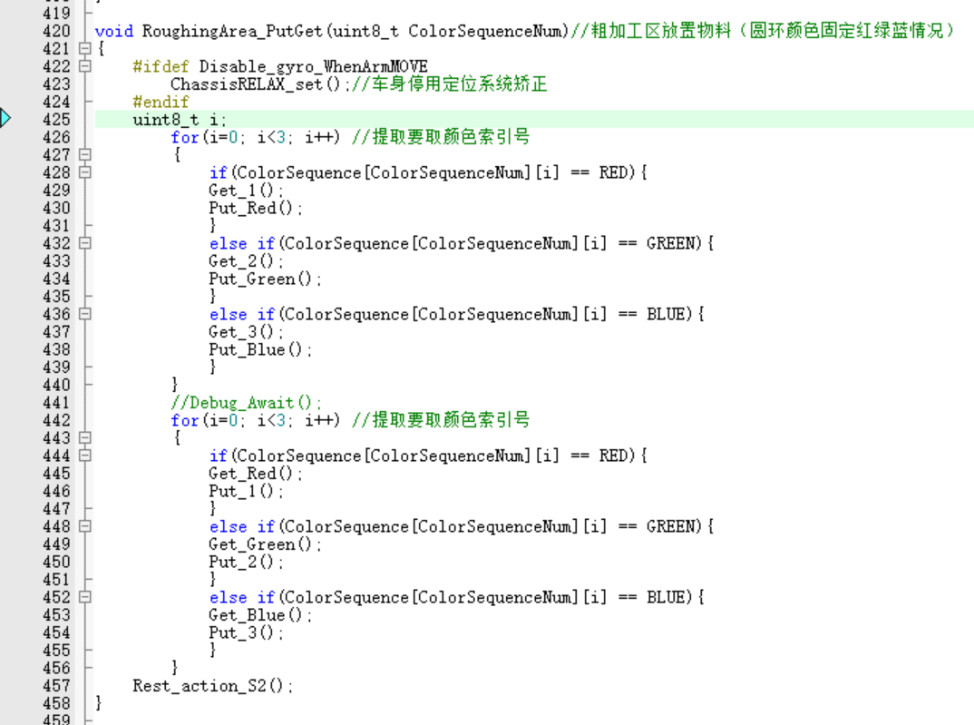
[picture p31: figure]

采用2个For循环，i由0加到2，实现内部的3次循环，执行了Get_1，Get_2，Get_3代表冲在料仓中取物料的动作组
Put_Red,Put_Green,Put_Blue表示放置到对应颜色色环的动作组。
426行for循环表示从料仓中取物料放置到色环。
442行for循环表示取回取对应色环的物料，放置达料仓中

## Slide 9

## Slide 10

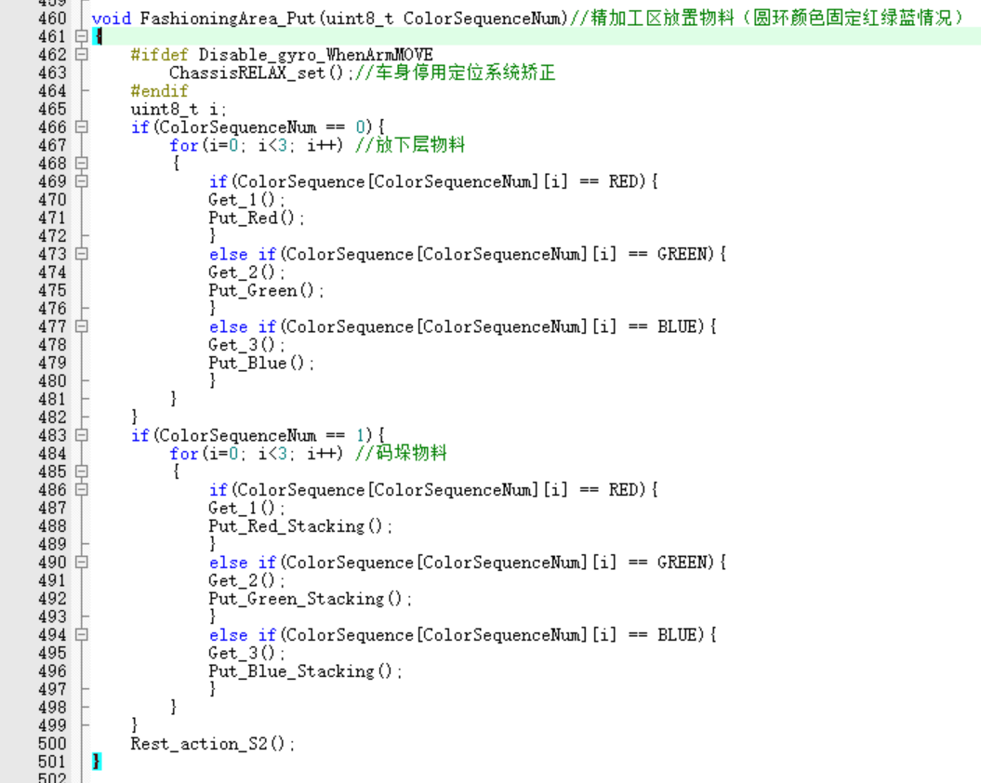
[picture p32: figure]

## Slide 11

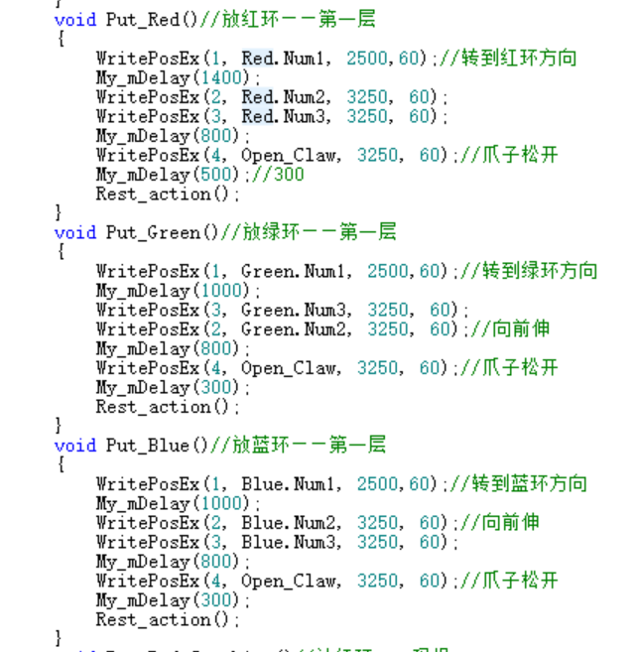
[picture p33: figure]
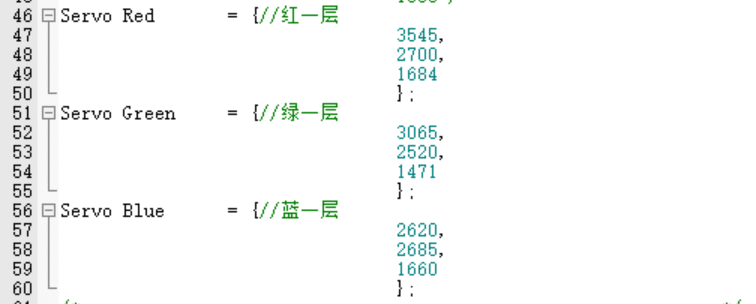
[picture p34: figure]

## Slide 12


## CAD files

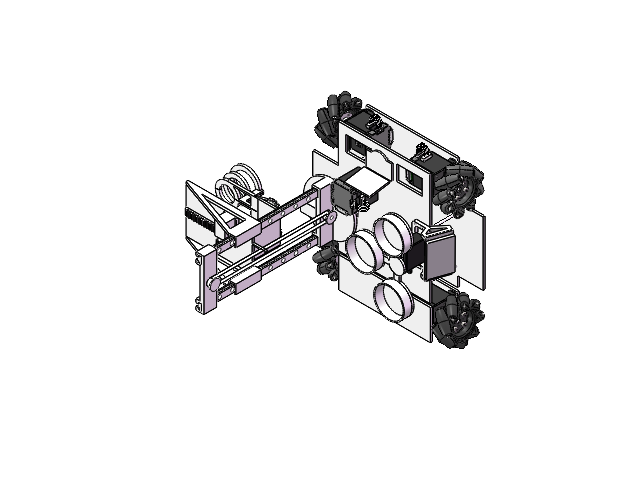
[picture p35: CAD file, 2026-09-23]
装配体1.SLDASM
下底板
D39 步进电机 x 5
D39 电机安装板 x 4
悬挂的上底板
悬挂下底板
J20 麦克纳姆轮76mm-L轮 x 2
J20 麦克纳姆轮76mm-R轮 x 2
滑块壳体1 x 2
8-19-6轴承1 x 2
零件3 x 2
螺纹轴
上底板
支架 x 4
J79 60齿带轮
J14 轴直径6长60
J09 内径6mm单轴承总装
内圈
外圈
机械臂下底盘
机械臂纵向支架 x 2
夹爪支架
夹爪真爪3
夹爪
夹爪前臂
夹爪前臂2
J79 20齿同步带轮
串口屏
耐烧舵机
金属舵盘
托盘
摄像头支架新
机械臂上方支架
机械臂传送带
夹爪支架齿条齿轮
齿条齿轮电机 x 3

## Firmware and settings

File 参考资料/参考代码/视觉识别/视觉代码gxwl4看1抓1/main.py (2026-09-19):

import sys
import serial
import cv2 as cv
import numpy as np
import time
import configparser
from threading import Thread
from maix import camera, display, image,pinmap,touchscreen,app,http
from detect_color import Color_detect
from find_circle import Find_circle
#   -------		串口通讯的规则为：	-------      
#   波特率115200		                        
#   下位机：帧头(1字节)0x1B	 数据(1字节)0x30     
#   上位机：数据(字符)       帧尾(1字节)0x0D     
#   ---------------------------------------	   
#   当接收到下位机数据后会发送'0x06'，表示命令已接收
# 0x30(停止)  0x32(物料颜色识别)  0x33(圆心坐标定位) 0x36(圆环颜色顺序)

html = """<!DOCTYPE html>
<html>
<head>
    <title>JPG Stream</title>
</head>
<body>
    <h1>MaixPy JPG Stream</h1>
    <img src="/stream" alt="Stream">
</body>
</html>"""

# 创建配置解析器
config = configparser.ConfigParser()
config.read('config.ini')
exposure = int(config.get('Settings', 'exposure'))
gain = int(config.get('Settings', 'gain'))

camera_width  = 240
camera_height = 240
cam = camera.Camera(camera_width,camera_height,fps=30)
cam.exposure(exposure)  #曝光时间
cam.gain(gain)       #增益
pinmap.set_pin_function("A18", "UART1_RX")
pinmap.set_pin_function("A19", "UART1_TX")
dis = display.Display()
img_back = image.load("/maixapp/share/icon/ret.png")
back_rect = [0, 0, 32, 32]
back_rect_disp = image.resize_map_pos(cam.width(), cam.height(), dis.width(), dis.height(), image.Fit.FIT_CONTAIN, back_rect[0], back_rect[1], back_rect[2], back_rect[3])
ts = touchscreen.TouchScreen()

device = "/dev/ttyS1"
ser = serial.Serial(device, 115200)
# print('serial test start ...')
response = None
Flag = True

def is_in_button(x, y, btn_pos):
    return x > btn_pos[0] and x < btn_pos[0] + btn_pos[2] and y > btn_pos[1] and y < btn_pos[1] + btn_pos[3]

def adjust(x,y):
    global config,exposure,gain
    if 0<exposure<40000:
        if 110<x<210 and 305<y<360:
            exposure = exposure - 1000
            gain = gain - 100
            cam.exposure(exposure)  #曝光时间
            cam.gain(gain)       #增益
        if 385<x<470 and 305<y<360:
            exposure = exposure + 1000
            gain = gain + 100
            cam.exposure(exposure)  #曝光时间
            cam.gain(gain)       #增益
        config.set('Settings', 'exposure', str(exposure))
        config.set('Settings', 'gain', str(gain))
    if 0<exposure<40000:
        with open('config.ini', 'w') as config_file:
            config.write(config_file)

def rece():
    global response, Flag
    #res = None

    while Flag:
        res = None
        while Flag:
            time.sleep(0.1)
            if ser.inWaiting():
                read_bytes = ser.read(1)
                # print(read_bytes)
                if res is None:
                    if read_bytes == b'\x1B':
                        res = read_bytes
                else:
                    res += read_bytes
                    if (len(res) == 2):
                        ser.write(b'\x06')
                        break

        if res != None:
            if res == b'\x1B\x30':
                response = None
            else:
                response = res


def remove(string):
    return string.replace(" ", "")

def main():
    global Flag
    Cdet = Color_detect()
    Fdet = Find_circle()
    t = Thread(target=rece)
    t.start()

    run_text = ''
    res_text = ''
    frame_tail = b'\x0D'
    QR_start = b'\x1B\x31'
    color_start = b'\x1B\x32'
    cir_start = b'\x1B\x33'
    Sequence_start = b'\x1B\x36'

    oi_x = 40
    oi_y = 40
    oi_w = 160
    oi_h = 160

    stream = http.JpegStreamer()
    stream.set_html(html)
    stream.start()
    #response = QR_start##################################################################################################
    lst = 0
    last_x,last_y = 0,0
    while not app.need_exit():
        try:
            img = cam.read()
            if response == None:
                jpg = img.to_jpeg()
                stream.write(jpg)
            if not img:
                time.sleep(0.001)
                continue
            st = time.time()
            run_t = int(1//round(st - lst, 4))
            lst = st
            frame = image.image2cv(img,ensure_bgr=True, copy=False)
            if response == QR_start:
                qrcodes = img.find_qrcodes()
                run_text = "QR"
                for qr in qrcodes:
                    corners = qr.corners()
                    for i in range(4):
                        img.draw_line(corners[i][0], corners[i][1], corners[(i + 1) % 4][0], corners[(i + 1) % 4][1], image.COLOR_RED)
                    img.draw_string(qr.x(), qr.y() - 15, qr.payload(), image.COLOR_RED)
                    res_text = qr.payload()
                    ser.write(res_text.encode()+frame_tail)
                else:
                    res_text = ""
            if response == color_start:
                # roi = img[y:y+h, x:x+w]
                C_text = Cdet.run(frame[oi_y:oi_y+oi_h,oi_x:oi_x+oi_w])
                run_text = "COLOR"
                if C_text:
                    res_text = C_text
                    # response = None
                    ser.write(res_text.encode()+frame_tail)
                else:
                    res_text = ""
                cv.rectangle(frame, (oi_x, oi_y),
                            (oi_x + oi_w, oi_y + oi_h), (0, 255, 0), 2)
            elif response == cir_start:

                # 需要检测的圆环颜色列表
                colors_to_detect = ["green"]# 最后一个值为通用，按需求使用"red", "blue", "green", "general"
                # 遍历颜色列表
                for color in colors_to_detect:
                    F_text = Fdet.find_circle_Pos(frame, color, debug=True)
                    if F_text:
                        # 如果找到，退出循环
                        break
                run_text = "CIRCLE"
                if F_text:
                    res_text = remove(str(F_text))
                    img.draw_circle(F_text[0], F_text[1], 2,image.Color.from_rgb(255, 0, 0),2)
                    ser.write(res_text.encode()+frame_tail)
                else:
                    res_text = ""
            elif response == Sequence_start: 
                F_text = Fdet.find_circle_Seq(frame, True)
                run_text = "Sequence"
                if F_text:
                    res_text = remove(str(F_text))
                    ser.write(res_text.encode()+frame_tail)
                else:
                    res_text = ""
            elif response == b'\x1B\x30':
                run_text = ""
                res_text = ""
            elif response is None:
                run_text = ""
                res_text = ""
            img.draw_string(125, 5,"RUN: {0}".format(run_text), color = image.COLOR_RED,scale=1)
            img.draw_string(125, 18,"RES:{0}".format(res_text), color = image.COLOR_RED,scale=1)
            img.draw_string(125, 31,"FPS: {0}".format(run_t), color = image.COLOR_RED,scale=1)
            img.draw_image(0, 0, img_back)
            img.draw_rect(0,210, 50, 30, color = image.COLOR_RED,thickness=3)
            img.draw_rect(190, 210,50,30, color = image.COLOR_BLUE,thickness=3)
            img.draw_string(9,212, '-', color = image.COLOR_GREEN,scale=2.5,thickness=2)
            img.draw_string(199, 212, '+', color = image.COLOR_GREEN,scale=2.5,thickness=2)
            dis.show(img)
            x, y, preesed = ts.read()
            if is_in_button(x, y, back_rect_disp):
                # 停止线程
                Flag = False
                t.join()  # 等待线程结束
                app.set_exit_flag(True)
            if last_x != x and last_y != y:
                adjust(x,y)
                time.sleep(0.01)
            last_x,last_y = x,y
        except:
            time.sleep(0.001)

if __name__ == '__main__':
    main()

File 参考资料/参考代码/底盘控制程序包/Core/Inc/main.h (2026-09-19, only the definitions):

#define POWER_Pin GPIO_PIN_2
#define POWER_GPIO_Port GPIOE
#define POWER_KEY_Pin GPIO_PIN_3
#define POWER_KEY_GPIO_Port GPIOE
#define KEY_Pin GPIO_PIN_4
#define KEY_GPIO_Port GPIOE
#define IN1_Pin GPIO_PIN_0
#define IN1_GPIO_Port GPIOC
#define IN2_Pin GPIO_PIN_1
#define IN2_GPIO_Port GPIOC
#define IN3_Pin GPIO_PIN_2
#define IN3_GPIO_Port GPIOC
#define LCD_CS_Pin GPIO_PIN_4
#define LCD_CS_GPIO_Port GPIOA
#define DC_Pin GPIO_PIN_6
#define DC_GPIO_Port GPIOA
#define LCD_RESET_Pin GPIO_PIN_4
#define LCD_RESET_GPIO_Port GPIOC
#define W25Qxx_CS_Pin GPIO_PIN_0
#define W25Qxx_CS_GPIO_Port GPIOB
#define KEY5_Pin GPIO_PIN_7
#define KEY5_GPIO_Port GPIOE
#define KEY4_Pin GPIO_PIN_8
#define KEY4_GPIO_Port GPIOE
#define KEY3_Pin GPIO_PIN_9
#define KEY3_GPIO_Port GPIOE
#define KEY2_Pin GPIO_PIN_10
#define KEY2_GPIO_Port GPIOE
#define KEY1_Pin GPIO_PIN_11
#define KEY1_GPIO_Port GPIOE
#define QB_Pin GPIO_PIN_12
#define QB_GPIO_Port GPIOE
#define VRS1_Pin GPIO_PIN_13
#define VRS1_GPIO_Port GPIOE
#define VRS2_Pin GPIO_PIN_14
#define VRS2_GPIO_Port GPIOE
#define VRS3_Pin GPIO_PIN_15
#define VRS3_GPIO_Port GPIOE
#define IR_2_Pin GPIO_PIN_14
#define IR_2_GPIO_Port GPIOB
#define IR_1_Pin GPIO_PIN_15
#define IR_1_GPIO_Port GPIOB
#define TRIG1_Pin GPIO_PIN_8
#define TRIG1_GPIO_Port GPIOD
#define TRIG2_Pin GPIO_PIN_9
#define TRIG2_GPIO_Port GPIOD
#define TRIG3_Pin GPIO_PIN_10
#define TRIG3_GPIO_Port GPIOD
#define TRIG4_Pin GPIO_PIN_11
#define TRIG4_GPIO_Port GPIOD
#define ECHO1_Pin GPIO_PIN_12
#define ECHO1_GPIO_Port GPIOD
#define ECHO1_EXTI_IRQn EXTI15_10_IRQn
#define ECHO2_Pin GPIO_PIN_13
#define ECHO2_GPIO_Port GPIOD
#define ECHO2_EXTI_IRQn EXTI15_10_IRQn
#define ECHO3_Pin GPIO_PIN_14
#define ECHO3_GPIO_Port GPIOD
#define ECHO3_EXTI_IRQn EXTI15_10_IRQn
#define ECHO4_Pin GPIO_PIN_15
#define ECHO4_GPIO_Port GPIOD
#define ECHO4_EXTI_IRQn EXTI15_10_IRQn
#define MAX3485_EN_Pin GPIO_PIN_8
#define MAX3485_EN_GPIO_Port GPIOC
#define RS485_EN_Pin GPIO_PIN_15
#define RS485_EN_GPIO_Port GPIOA
#define LED1_Pin GPIO_PIN_3
#define LED1_GPIO_Port GPIOD
#define LED2_Pin GPIO_PIN_4
#define LED2_GPIO_Port GPIOD

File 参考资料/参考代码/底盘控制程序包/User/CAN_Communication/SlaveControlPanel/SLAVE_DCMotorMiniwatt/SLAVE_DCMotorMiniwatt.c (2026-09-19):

/* 包含头文件 ----------------------------------------------------------------*/
#include "SLAVE_DCMotorMiniwatt/SLAVE_DCMotorMiniwatt.h"
#include "string.h"
#include "CAN_Communication.h"
/* 私有类型定义 --------------------------------------------------------------*/

/* 私有宏定义 ----------------------------------------------------------------*/

/* 私有变量 ------------------------------------------------------------------*/
static DCMotorMiniwattDef_t* head_handle = NULL;
/* 扩展变量 ------------------------------------------------------------------*/

/* 私有函数原形 --------------------------------------------------------------*/

/* 函数体 --------------------------------------------------------------------*/

static uint16_t SLAVE_DCMotorMiniwatt_ProtocolDefinitions(DCMotorMiniwattDef_t* handle,
                                       uint16_t cannum,
                                       PgnCanTxDataType *head)
{
    uint16_t cannum_buff;
    cannum_buff = cannum;

    handle->CAN_Number = cannum_buff; //第一个帧的CAN编号，后面以次累加计算
#ifndef DCMOTOR_NEW
    head[cannum_buff++] = xCreate(  DEVICE_ID,DEVICE_LIST,
									MotorPlate_Addr,
									handle->Motor_SerialNumber.DATE.Serial_Number,
									2,2,
                                    FALSE,PG_TX_FREE,MODE_REQ,TT_ASYNC,50,0,
                                    handle->Motor_SerialNumber.Datum,PG_RXMOTOR_SERIAL_NUMBER_LEN,
									handle->Motor_SerialNumber.Datum,PG_RXMOTOR_SERIAL_NUMBER_LEN); //序号修改
	head[cannum_buff-1].ch = 1;
#else
	head[cannum_buff++] = xCreate(  DEVICE_ID,DEVICE_LIST,
									MotorPlate_Addr,
	                                handle->Motor_ControlData1.Data_id.id,
									1,1,
                                    TRUE,PG_TX_FREE,MODE_BRO,TT_ASYNC,10,0,
                                    handle->Motor_ControlData1.Datum,PG_RXMOTORDATA1_LEN,
									handle->Motor_ControlData1_Ack.Datum,PG_DCMOTORCTRL_DATA1_STE_ACK_LEN); //控制数据1帧初始化
	head[cannum_buff-1].ch = 1;
#endif
    head[cannum_buff++] = xCreate(  ALL_Addr,0,
									MotorPlate_Addr,
	                            #ifndef DCMOTOR_NEW
									handle->Motor_SerialNumber.DATE.Serial_Number,
	                            #else
	                                handle->Motor_ControlData1.Data_id.id,
	                            #endif
									0,0,
                                    FALSE,PG_TX_FREE,MODE_BRO,TT_CYCLIC,10,0,
                                    0,0,
									handle->Motor_UploadData.Datum,PG_TXMOTORDATA_LEN); //反馈数据帧初始化
	head[cannum_buff-1].ch = 1;

    head[cannum_buff++] = xCreate(  DEVICE_ID,DEVICE_LIST,
									MotorPlate_Addr,
								#ifndef DCMOTOR_NEW
									handle->Motor_SerialNumber.DATE.Serial_Number,
								#else
	                                handle->Motor_ControlData1.Data_id.id,
	                            #endif
									0,0,
                                    TRUE,PG_TX_REQ,MODE_BRO,TT_CYCLIC,10,0,
                                    handle->Motor_ControlData.Datum,PG_RXMOTORDATA_LEN,
									0,0); //控制数据帧初始化
	head[cannum_buff-1].ch = 1;

    return cannum_buff;
}

uint16_t SLAVE_DCMotorMiniwatt_CANinit(uint16_t cannum,void *head)
{
	DCMotorMiniwattDef_t* target;
	uint16_t cannum_buff;
	cannum_buff = cannum;
    
	for(target=head_handle; target; target=target->next) 
	{
			cannum_buff = SLAVE_DCMotorMiniwatt_ProtocolDefinitions(target,cannum_buff,((PgnCanTxDataType*)head));
	}
    
	return cannum_buff;
}

uint8_t SLAVE_DCMotorMiniwatt_Init(DCMotorMiniwattDef_t* handle,uint8_t list)
{
	DCMotorMiniwattDef_t* target = head_handle;
    
    memset(handle, 0, sizeof(DCMotorMiniwattDef_t));
    
	#ifndef DCMOTOR_NEW
		handle->Motor_SerialNumber.DATE.Serial_Number = list;
	#else
		handle->Motor_ControlData1.Data_id.id = list;
	#endif
    //电机速度： 0.5 rpm/位递增，从-16000 rpm开始计算，范围-16000 rpm到16000 rpm),0rpm计算得出32000;
    handle->Motor_ControlData.DATE.SetSpeed = 32000;
    handle->Motor_ControlData.DATE.SetPwm = 0;
    handle->Motor_UploadData.DATE.Speed = 32000;
    
	while(target) 
    {
		if(target == handle) 
            return 0;	//already exist.
		target = target->next;
	}
	handle->next = head_handle;
	head_handle = handle;
	return 1;
}

void SLAVE_DCMotorMiniwatt_NumberSet(DCMotorMiniwattDef_t* handle,uint8_t number)
{
    if(number > 15)
    {
        number = 15;
    }
	
	#ifndef DCMOTOR_NEW
		handle->Motor_SerialNumber.DATE.Serial_Number = number;
	#else
		handle->Motor_ControlData1.Data_id.id = number;
	    handle->Motor_ControlData1.Data_id.order = 0x01;
	#endif
    
    CAN_TT_ASYNC_Enable(handle->CAN_Number);
}
#ifndef DCMOTOR_NEW
uint16_t SLAVE_DCMotorMiniwatt_PlaceRead(DCMotorMiniwattDef_t* handle)
{
	return handle->Motor_UploadData.DATE.Coded_Value;	
}
#else
int32_t SLAVE_DCMotorMiniwatt_PlaceRead(DCMotorMiniwattDef_t* handle)
{
	return ((handle->Motor_UploadData.DATE.Coded_Value_H<<16) | handle->Motor_UploadData.DATE.Coded_Value_L);	
}
#endif


int16_t SLAVE_DCMotorMiniwatt_SpeedRead(DCMotorMiniwattDef_t* handle)
{
    int16_t val;
    val = (handle->Motor_UploadData.DATE.Speed/2)-16000;
    
    return val;
}

void SLAVE_DCMotorMiniwatt_SpeedSet(DCMotorMiniwattDef_t* handle,int16_t val)
{
	handle->Motor_ControlData.DATE.SetPwm = 0;
	handle->Motor_ControlData.DATE.SetSpeed = (val+16000)*2;
#ifdef DCMOTOR_NEW
	handle->Motor_ControlData.DATE.SetCurr = 0;
	if(val != 0)
		handle->Motor_ControlData.DATE.SetLocation = 0;
#endif	
}
void SLAVE_DCMotorMiniwatt_PWMSet(DCMotorMiniwattDef_t* handle,int16_t val)
{
	handle->Motor_ControlData.DATE.SetPwm = val;
	handle->Motor_ControlData.DATE.SetSpeed = 32000;
#ifdef DCMOTOR_NEW
	handle->Motor_ControlData.DATE.SetCurr = 0;
	handle->Motor_ControlData.DATE.SetLocation = 0;
#endif
}
#ifdef DCMOTOR_NEW
void SLAVE_DCMotorMiniwatt_CurrSet(DCMotorMiniwattDef_t* handle,int16_t val)
{
	handle->Motor_ControlData.DATE.SetCurr = val;
	handle->Motor_ControlData.DATE.SetSpeed = 32000;
	handle->Motor_ControlData.DATE.SetPwm = 0;
	handle->Motor_ControlData.DATE.SetLocation = 0;
}
void SLAVE_DCMotorMiniwatt_LocationSet(DCMotorMiniwattDef_t* handle,int16_t val)
{
        handle->Motor_ControlData.DATE.SetCurr = 0;
        handle->Motor_ControlData.DATE.SetSpeed = 32000;
	    handle->Motor_ControlData.DATE.SetPwm = 0;
	    handle->Motor_ControlData.DATE.SetLocation = val;
}
void SLAVE_DCMotorMiniwatt_Digital_PWMSet(DCMotorMiniwattDef_t* handle,int16_t val)
{
	handle->Motor_ControlData1.Data_pwm.pwm = val;
	handle->Motor_ControlData1.Data_pwm.order = 0x02;
    CAN_TT_ASYNC_Enable(handle->CAN_Number);
}
void SLAVE_DCMotorMiniwatt_Digital_SpeedSet(DCMotorMiniwattDef_t* handle,int16_t val)
{
	handle->Motor_ControlData1.Data_speed.speed = val;
	handle->Motor_ControlData1.Data_speed.order = 0x03;
    CAN_TT_ASYNC_Enable(handle->CAN_Number);
}
void SLAVE_DCMotorMiniwatt_Digital_LocationSet(DCMotorMiniwattDef_t* handle,int32_t val)
{
	handle->Motor_ControlData1.Data_location.location = val;
	handle->Motor_ControlData1.Data_location.order = 0x04;
    CAN_TT_ASYNC_Enable(handle->CAN_Number);
}
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

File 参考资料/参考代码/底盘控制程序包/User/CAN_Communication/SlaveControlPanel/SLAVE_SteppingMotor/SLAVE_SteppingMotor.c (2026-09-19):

/* 包含头文件 ----------------------------------------------------------------*/
#include "SLAVE_SteppingMotor/SLAVE_SteppingMotor.h"
#include "string.h"
#include "CAN_Communication.h"
/* 私有类型定义 --------------------------------------------------------------*/

/* 私有宏定义 ----------------------------------------------------------------*/

/* 私有变量 ------------------------------------------------------------------*/
static SteppingMotorDef_t* head_handle = NULL;
/* 扩展变量 ------------------------------------------------------------------*/

/* 私有函数原形 --------------------------------------------------------------*/

/* 函数体 --------------------------------------------------------------------*/
static uint16_t SLAVE_SteppingMotor_ProtocolDefinitions(SteppingMotorDef_t* handle,
                                                   uint16_t cannum,
                                                   PgnCanTxDataType *head)
{
    uint16_t cannum_buff;
    cannum_buff = cannum;
    
    handle->CAN_Number = cannum_buff; //第一个帧的CAN编号，后面以次累加计算
    
    head[cannum_buff++] = xCreate( DEVICE_ID,DEVICE_LIST,
								   SLAVE_SteppingMotorPlate_Addr,
	                               handle->SteppingMotor_SerialNumber.DATE.Serial_Number,
	                               1,1,
                                   TRUE,PG_TX_FREE,MODE_REQ,TT_ASYNC,10,0,  
                                   handle->SteppingMotor_SerialNumber.Datum,PG_RXSTEPPINGMOTOR_SERIAL_NUMBER_LEN,
	                               handle->SteppingMotor_SerialNumber.Datum,PG_RXSTEPPINGMOTOR_SERIAL_NUMBER_LEN); //序号修改    
    head[cannum_buff-1].ch = 1;                              
    head[cannum_buff++] = xCreate( ALL_Addr,0,
	                               SLAVE_SteppingMotorPlate_Addr,
	                               handle->SteppingMotor_SerialNumber.DATE.Serial_Number,
	                               0,0,   
                                   FALSE,PG_TX_FREE,MODE_BRO,TT_CYCLIC,10,0,   
                                   0,0,
	                               handle->SteppingMotor_UploadData.Datum,PG_TXSTEPPINGMOTORDATA_LEN); //数据反馈       
    head[cannum_buff-1].ch = 1;                              
    head[cannum_buff++] = xCreate( DEVICE_ID,DEVICE_LIST,
	                               SLAVE_SteppingMotorPlate_Addr,
								   handle->SteppingMotor_SerialNumber.DATE.Serial_Number,
								   0,0,   
                                   TRUE,PG_TX_FREE,MODE_REQ,TT_ASYNC,10,0,   
                                   handle->SteppingMotor_ControlData.Datum,PG_SETSTEPPINGMOTORDATA_LEN,
								   handle->SteppingMotor_ControlDataAck.Datum,PG_ACKSTEPPINGMOTORDATA_LEN); //控制数据帧初始化                                       
    head[cannum_buff-1].ch = 1;
	
    return cannum_buff;
}

uint16_t SLAVE_SteppingMotorg_CANinit(uint16_t cannum,void *head)
{
    SteppingMotorDef_t* target;
    uint16_t cannum_buff;
    cannum_buff = cannum;
    
	for(target=head_handle; target; target=target->next) 
    {
        cannum_buff = SLAVE_SteppingMotor_ProtocolDefinitions(target,cannum_buff,((PgnCanTxDataType*)head));
	}
    
    return cannum_buff;
}

uint8_t SLAVE_SteppingMotor_Init(SteppingMotorDef_t* handle,uint8_t list)
{
	SteppingMotorDef_t* target = head_handle;
    
    memset(handle, 0, sizeof(SteppingMotorDef_t));
    
    handle->SteppingMotor_SerialNumber.DATE.Serial_Number = list;
    
	while(target) 
    {
		if(target == handle) 
            return 0;	//already exist.
		target = target->next;
	}
	handle->next = head_handle;
	head_handle = handle;
    
	return 1;
}


void SLAVE_SteppingMotor_NumberSet(SteppingMotorDef_t* handle,uint8_t number)
{
    if(number > 15)
    {
        number = 15;
    }
    
    CAN_TT_ASYNC_Enable(handle->CAN_Number);
}


uint8_t SLAVE_SteppingMotor_ReadEnabledState(SteppingMotorDef_t* handle)
{
    return handle->SteppingMotor_UploadData.DATE.enabled_state;
}

uint8_t SLAVE_SteppingMotor_ReadRunState(SteppingMotorDef_t* handle)
{
    return handle->SteppingMotor_UploadData.DATE.run_state;
}

uint8_t SLAVE_SteppingMotor_Control(SteppingMotorDef_t* handle,
                                    int16_t  speed_v0,     
                                    int16_t  speed_vt,     
                                    uint16_t step_out,     
                                    uint16_t EnabledTime_MAX
                                   )
{
    uint8_t err;
    
    err = 0;
    if((handle->SteppingMotor_UploadData.DATE.run_state == RUNSTA_STEP)&&(speed_vt != 0))
    {
        err = 1;
    }
    else if ((handle->SteppingMotor_UploadData.DATE.run_state == RUNSTA_SPEED)
           &&(step_out != 0))
    {
        err = 1;
    }
    else
    {
        handle->SteppingMotor_ControlDataAck.DATE.ack = ACK_START;
        handle->SteppingMotor_ControlData.DATE.speed_v0 = speed_v0;
        handle->SteppingMotor_ControlData.DATE.speed_vt = speed_vt;
        handle->SteppingMotor_ControlData.DATE.step_out = step_out;
        handle->SteppingMotor_ControlData.DATE.EnabledTime_MAX = EnabledTime_MAX;
    }
    
    CAN_TT_ASYNC_Enable(handle->CAN_Number+2);
    
    return err;
}

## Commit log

2026-09-19 添加项目协作目录结构：代码、设计图、参考资料、规则说明与注意事项
2026-09-19 添加 .gitignore：忽略 Keil/STM32CubeMX 编译产物、用户配置及 Python 缓存
2026-09-19 完善 README 与各目录说明文档
2026-09-19 上传项目资料：代码、参考资料、设计图与规则说明（不含视频）
    [课程计划(参考).xlsx]
2026-09-19 重组织目录：代码与设计图移入参考资料（参考代码/参考设计图），删除非必要文件
    [课程计划(参考).xlsx]
2026-09-19 恢复 代码 与 设计图 目录（仅含 README 说明，供后续开发使用）
2026-09-23 上传 规则说明.pdf
2026-09-23 上传 评分标准.pdf
2026-09-23 上传 02-底盘路径规划定位及速度控制.md
2026-09-23 上传 03-机械臂控制方案.md
2026-09-23 上传 05-避障控制决策.md
2026-09-23 上传 09-软件算法设计总结.md
2026-09-23 上传 电控关键技术与创新点.md
2026-10-23 Add electrical test projects and unified chassis debugging manual
2026-10-25 Fix chassis wheel map and document M6 M7 sync frames

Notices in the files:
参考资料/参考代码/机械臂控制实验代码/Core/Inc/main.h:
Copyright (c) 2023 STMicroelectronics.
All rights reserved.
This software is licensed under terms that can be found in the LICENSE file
